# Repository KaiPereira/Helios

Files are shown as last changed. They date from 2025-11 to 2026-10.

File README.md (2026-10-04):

# Helios - Solar Powered LoRa Weather Station

Photo of Helios

Helios is a small, solar powered LoRa weather station, in Pi Zero 2W form factor! It's designed for extremely low power consumption, small price, expandability and hobby purposes! It has a couple onboard sensors for temperature, humidity, pressure and light, but it's mostly designed to be your own little customizable node!

## Custom Features
- 150MHz to 960MHz LoRa SMA antenna, up to +22 dBm
- Solar powered battery charging up to 18V
- 300mA peak power consumption
- Pi Zero 2W form factor
- USB-C programming and power
- 20 programmable GPIO's for expandability
- Temperature, humidity, pressure and ambient light sensors

## PCB Design

Helios is designed to be a low-cost PCB and is a 4 layer PCB, with a SIGNAL/GND/PWR/SIGNAL stackup! 




It's built off the STM32L072 MCU, using the SX1262 LoRa transceiver with the 0900FM filter and the PE4259 RF switch! It's a classic SMA antenna that broadcasts temperature, humidity, pressure and ambient light from the BME280 and BH1750! 

The board can be powered off of USB-C, or solar powered battery charging with the SPV1050 alongside very minimal power usage!






## Manufacturing

The PCB is fairly simple to manufacture. You can get them from JLC, PCBWay or hand-solder it with a stencil and hotplate! If you want the board to be cheaper, just remove the sensors and other unnecessary things you don't need.

The gerbers (PCB.zip), BOM and CPL are located in the [production folder](/TRANSCEIVER_PCB/production/), and there's also a link to the solar panels and battery I used for the project! I got the boards manufactured by PCBWay, so there's a PCBWay specific BOM in that directory too!

I've created a very minimal case for this project if you want to keep it waterproof while having it active outside, and you can view all the files for that in the [CAD folder](https://github.com/KaiPereira/Helios/tree/master/CAD)! Here's an [Onshape link](https://cad.onshape.com/documents/da47fca73387cbfcd2fcd0da/w/e0853c342d07596ecafe782f/e/20c20d8fae7f9e025aea9deb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) too!

## Firmware

Programming the board is really simple! Customize the firmware to your liking, plug in the USB-C and then run:

```
pio run -t upload
```

## Contributions

Thanks so much to PCBWay and Hack Club for sponsoring this project! Another big thanks to the guys in the KiCad discord server for their help and reviews of the board :D

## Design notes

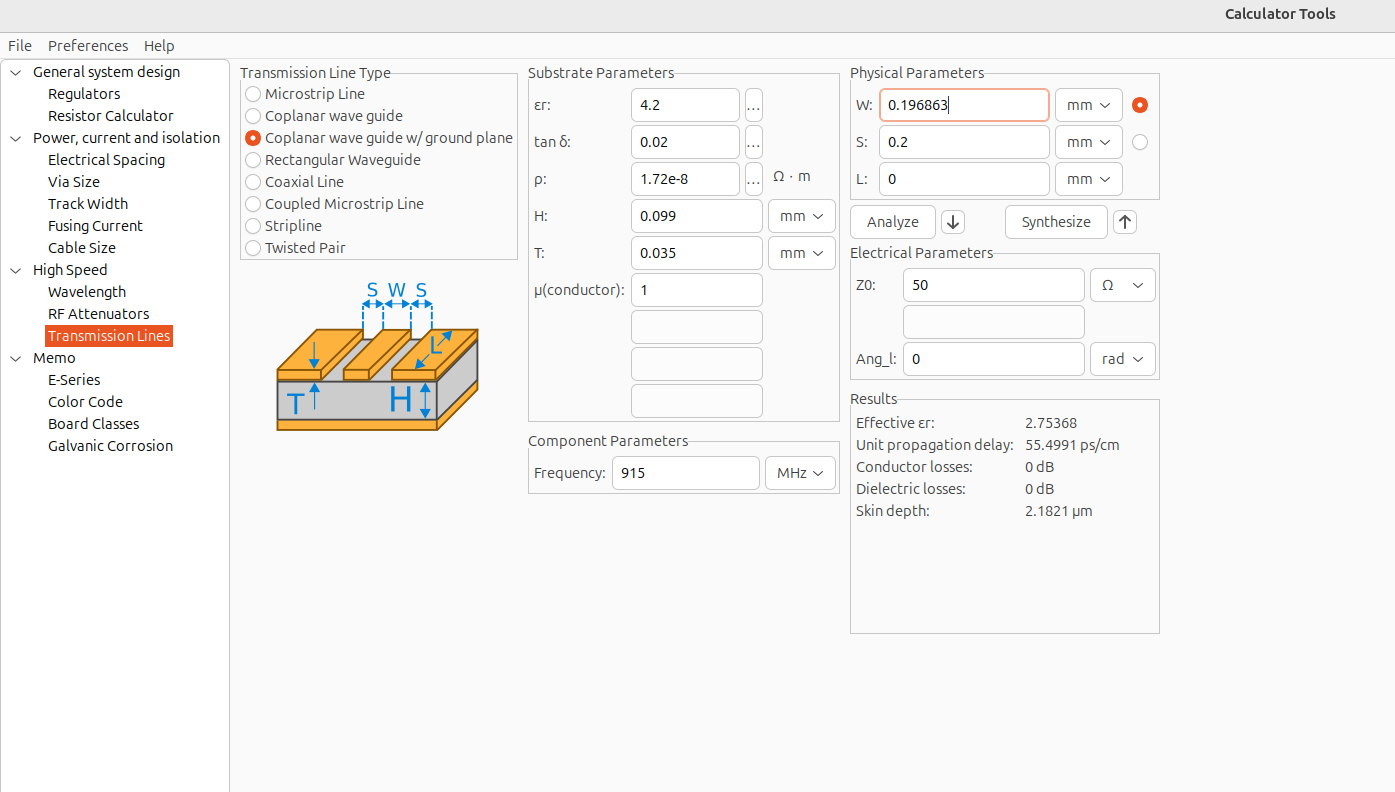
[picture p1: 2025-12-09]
images/Pasted image 20251208185241.png

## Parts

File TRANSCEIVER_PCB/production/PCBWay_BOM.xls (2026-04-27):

PCBWay Bom Quotation, Product No.:T-1K5W971089A
Item # | *Designator | *Qty | Manufacturer | *Mfg Part # | Description / Value | Vendor Part # | *Package/Footprint | Your Instructions / Notes | *Unit Price(5 units) | *Total | *Delivery Time | *Actual Purchase Mfg Part # | *PCBWay Note | Customer Reply | PCBWay Update
1 | C1, C17, C18 | 3 | Samsung Electro-Mechanics | CL10B105MO8NNWC | 1uF | 1276-6524-1-ND | 603 |  | $0.074 | $1.110
2 | C10 | 1 | KEMET | C0402C103K3REC7411 | 10nF | 399-C0402C103K3REC7411CT-ND | 402 |  | $0.158 | $0.790
3 | C11, C13, C19, C2, C20, C29, C30, C31, C32, C4, C5, C6, C7, C8 | 14 | Murata Electronics | GRM155R71H104KE14J | 0.1uF | 490-13342-1-ND | 402 |  | $0.008 | $0.560
4 | C12, C14, C3 | 3 | Samsung Electro-Mechanics | CL21A475KAQNNNE | 4.7uF | 1276-1244-1-ND | 805 |  | $0.074 | $1.110
5 | C15, C16 | 2 | Murata Electronics | GJM1555C1H180GB01D | 18pF | 490-8082-1-ND | 402 |  | $0.101 | $1.010
6 | C21 | 1 | Samsung Electro-Mechanics | CL10B474KO8VPJC | 470nF | 1276-CL10B474KO8VPJCCT-ND | 603 |  | $0.231 | $1.155
7 | C22 | 1 | KEMET | C0402C102K5RECTU | 1nF | 399-C0402C102K5RECTUCT-ND | 402 |  | $0.158 | $0.790
8 | C23 | 1 | Murata Electronics | GRM1555C1H390JA01D | 39pF | 490-5871-1-ND | 402 |  | $0.158 | $0.790
9 | C24, C25 | 2 | Murata Electronics | GRM1555C2A3R3CA01D | 3.3pF | 490-7287-1-ND | 402 |  | $0.095 | $0.950
10 | C26 | 1 | KEMET | C0603C473K4RECAUTO | 47nF | 399-17881-1-ND | 603 |  | $0.368 | $1.840
11 | C27 | 1 | YAGEO | CC0402JRNPO9BN470 | 47pF | 311-1021-1-ND | 402 |  | $0.126 | $0.630
12 | C28, C33 | 2 | Samsung Electro-Mechanics | CL05C080DB51PNC | 8pF | 1276-CL05C080DB51PNCCT-ND | 402 |  | $0.095 | $0.950
13 | C9 | 1 | Panasonic Industry | EEH-ZC1V470P | 47uF | P15473CT-ND | C_Elec_6.3x5.4 |  | $2.205 | $11.025
14 | D1, D2, D3, D5 | 4 | Shenzhen Slkormicro Semicon Co., Ltd. | 1N5819WS | 1N5819WS | 5399-1N5819WSCT-ND | D_SOD-323 |  | $0.041 | $0.820
15 | D4 | 1 | Würth Elektronik | 150060VS75003 | LED | 732-150060VS75003CT-ND | 603 |  | $0.656 | $3.280 | 7-10 Workdays
16 | FB1, FB2 | 2 | Shenzhen Sunlord Electronics Co., Ltd. | GZ1608E601TF | GZ1608D601TF | 3442-GZ1608E601TFCT-ND | 603 |  | $0.011 | $0.110 |  |  | The quoted part number is [GZ1608E601TF], not [GZ1608D601TF] as specified in description
17 | FL1 | 1 | Johanson Technology Inc. | 0900FM15K0039001E | 0900FM15K0039E | 712-0900FM15K0039001ECT-ND | Balun_Johanson_0900FM15K0039 |  | $1.316 | $6.580 | 7-10 Workdays |  | The quoted part number is [0900FM15K0039001E], not [0900FM15K0039E] as specified in description
18 | J1 | 1 | GCT | USB4105-GF-A-120 | USB_C_Receptacle_USB2.0_16P | 2073-USB4105-GF-A-120CT-ND | USB_C_Receptacle_HRO_TYPE-C-31-M-12 |  | $0.978 | $4.890 |  |  | The quoted part number is [USB4105-GF-A-120], not [TYPE-C-31-M-12] as specified in description
19 | J2 | 1 | Amphenol Anytek | YO0201500000G | Screw_Terminal_01x02 | 609-4725-ND | TerminalBlock_Phoenix_PT-1,5-2-3.5-H_1x02_P3.50mm_Horizontal |  | $1.031 | $5.155
20 | J3 | 1 | JST Sales America Inc. | B2B-PH-K-S | Conn_01x02 | 455-1704-ND | JST_PH_B2B-PH-K_1x02_P2.00mm_Vertical |  | $0.201 | $1.005
21 | J4 | 1 | Molex | 0732511153 | LoRa Antenna | 900-0732511153-ND | SMA_Molex_73251-1153_EdgeMount_Horizontal |  | $6.611 | $33.055 | 7-10 Workdays
22 | J6 | 1 | Würth Elektronik | 61304021121 | Conn_02x20_Odd_Even | 732-5310-ND | PinHeader_2x20_P2.54mm_Vertical |  | $1.896 | $9.480
23 | L1 | 1 | Shenzhen Sunlord Electronics Co., Ltd. | MWSA0402S-220MT | 22uH | 3442-MWSA0402S-220MTCT-ND | L_Sunlord_MWSA0402S |  | $0.193 | $0.965
24 | L2 | 1 | TDK | MLZ2012M150WT000 | 15uH | 445-6397-1-ND | L_TDK_MLZ2012_h1.25mm |  | $0.171 | $0.855
25 | L3 | 1 | Murata Electronics | LQW15AN9N1G0ZD | 9.1nH | 490-LQW15AN9N1G0ZDCT-ND | 402 |  | $0.161 | $0.805
26 | L4 | 1 | Murata Electronics | LQW18AN47NJ00D | 47nH | 490-6895-1-ND | 603 |  | $0.121 | $0.605
27 | R1, R11, R12 | 3 | YAGEO | RC0402FR-0710KL | 10K | 311-10.0KLRCT-ND | 402 |  | $0.015 | $0.225
28 | R10 | 1 | YAGEO | RC0402FR-07100RL | 100 | 311-100LRCT-ND | 402 |  | $0.032 | $0.160
29 | R15, R2, R3 | 3 | YAGEO | RC0402FR-075K1L | 5.1k | 311-5.10KLRCT-ND | 402 |  | $0.015 | $0.225
30 | R4 | 1 | Stackpole Electronics Inc | RMCF0603FT10M0 | 10M | RMCF0603FT10M0CT-ND | 603 |  | $0.053 | $0.265
31 | R5 | 1 | YAGEO | RC0402FR-071ML | 1M | 311-1.00MLRCT-ND | 402 |  | $0.032 | $0.160
32 | R6 | 1 | Panasonic Industry | ERJ-2GEJ565X | 5.6M | P5.6MJCT-ND | 402 |  | $0.116 | $0.580
33 | R7 | 1 | YAGEO | RC0402FR-076M2L | 6.2M | 13-RC0402FR-076M2LCT-ND | 402 |  | $0.032 | $0.160
34 | R8 | 1 | YAGEO | RC0603JR-07510KL | 510K | 311-510KGRCT-ND | 603 |  | $0.053 | $0.265
35 | R9 | 1 | YAGEO | RC0402FR-072M7L | 2.7M | 13-RC0402FR-072M7LCT-ND | 402 |  | $0.032 | $0.160
36 | SW1, SW2 | 2 | Alps Alpine | SKRPACE010 | SKRPACE010 | 4809-SKRPACE010CT-ND | SW_Push_SPST_NO_Alps_SKRK |  | $0.091 | $0.910
37 | TP1, TP2, TP3, TP4, TP5, TP6, TP7, TP8 | 8 |  |  | TestPoint |  | TestPoint_Pad_D1.5mm | [DNP ]; |  |  |  |  | [DNP ];
38 | TP9 | 1 |  |  | Charging TP |  | TestPoint_Pad_D1.5mm | [DNP ]; |  |  |  |  | [DNP ];
39 | U1 | 1 | STMicroelectronics | STM32L072CBT6 | STM32L072CBT6 | 497-17503-ND | LQFP-48_7x7mm_P0.5mm |  | $2.777 | $13.885
40 | U3 | 1 | STMicroelectronics | SPV1050TTR | SPV1050TTR | 497-15978-1-ND | WQFN-20-1EP_3x3mm_P0.4mm_EP1.7x1.7mm |  | $3.260 | $16.300
41 | U4 | 1 | Semtech Corporation | SX1262IMLTRT | SX1262IMLTRT | SX1262IMLTRTCT-ND | QFN-24-1EP_4x4mm_P0.5mm_EP2.6x2.6mm |  | $3.019 | $15.095
42 | U5 | 1 | Torex Semiconductor Ltd | XC6206P332MR-G | XC6206P332MR-G | 893-XC6206P332MR-GCT-ND | SOT-23-3 |  | $0.262 | $1.310
43 | U6 | 1 | pSemi | 4259-63 | PE4259-63 | 1046-1011-1-ND | SOT-363_SC-70-6 |  | $1.092 | $5.460
44 | U8 | 1 | Rohm Semiconductor | BH1750FVI-TR | BH1750FVI | BH1750FVICT-ND | WSOF-6_L2.6-W1.6-P0.50-TL-EP |  | $1.087 | $5.435
45 | U9 | 1 | Bosch Sensortec | BME280 | BME280 | 828-1063-1-ND | Bosch_LGA-8_2.5x2.5mm_P0.65mm_ClockwisePinNumbering |  | $5.555 | $27.775
46 | Y1 | 1 | EPSON | FC-135 32.7680KA-A5 | 32.768 kHz | SER4103CT-ND | Crystal_SMD_3215-2Pin_3.2x1.5mm |  | $0.845 | $4.225
47 | Y2 | 1 | ECS Inc. | ECS-320-8-37B-CKY-TR | 32MHz | 50-ECS-320-8-37B-CKY-TRCT-ND | Crystal_SMD_2016-4Pin_2.0x1.6mm |  | $0.656 | $3.280 | 7-10 Workdays
48 |  | 1 | Molex | 2161960001 | BIG ANTENNNNAAA | 900-2161960001-ND | LoRa SMA Molex Antenna | 900-2161960001-ND(the SMA Molex Antenna) screwed onto the SMA connector (900-0732511153-ND) | $10.147 | $50.735 | 7-10 Workdays | 216196-0001
49 |  | 1 | JST Sales America Inc. | PHR-2 |  | 455-1165-ND | JST PHR connector (for battery I chose) | [DNP ]; |  |  |  |  | [DNP ];
50 |  | 1 | JST Sales America Inc. | BPH-002T-P0.5S |  | 455-BPH-002T-P0.5S-ND | JST PHR metal contacts (for PHR connector) | [DNP ]; |  |  |  |  | [DNP ];
51 |  | 4 | E-Z LOK | HI-002-WH |  | 5519-HI-002-WH-ND | Heatset Inserts | [DNP ]; |  |  |  |  | [DNP ];
 |  |  |  |  |  |  |  |  | Component Cost | $236.93
 |  |  |  |  |  |  |  |  | Assembly Cost | $29.00
 |  |  |  |  |  |  |  |  | PCB Cost | $25.97
 |  |  |  |  |  |  |  |  | V1 Member 1% off | -$0.55
 |  |  |  |  |  |  |  |  | All Total 5 Units | $291.35

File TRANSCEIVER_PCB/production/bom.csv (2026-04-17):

Designator | Footprint | Quantity | Value | LCSC Part #
C1, C17, C18 | 0603 | 3 | 1uF
C10 | 0402 | 1 | 10nF
C11, C13, C19, C2, C20, C29, C30, C31, C32, C4, C5, C6, C7, C8 | 0402 | 14 | 0.1uF
C12, C14, C3 | 0805 | 3 | 4.7uF
C15, C16 | 0402 | 2 | 18pF
C21 | 0603 | 1 | 470nF
C22 | 0402 | 1 | 1nF
C23 | 0402 | 1 | 39pF
C24, C25 | 0402 | 2 | 3.3pF
C26 | 0603 | 1 | 47nF
C27 | 0402 | 1 | 47pF
C28, C33 | 0402 | 2 | 8pF
C9 | C_Elec_6.3x5.4 | 1 | 47uF
D1, D2, D3, D5 | D_SOD-323 | 4 | 1N5819WS
D4 | 0603 | 1 | LED
FB1, FB2 | 0603 | 2 | GZ1608D601TF
FL1 | Balun_Johanson_0900FM15K0039 | 1 | 0900FM15K0039E
J1 | USB_C_Receptacle_HRO_TYPE-C-31-M-12 | 1 | USB_C_Receptacle_USB2.0_16P
J2 | TerminalBlock_Phoenix_PT-1,5-2-3.5-H_1x02_P3.50mm_Horizontal | 1 | Screw_Terminal_01x02
J3 | JST_PH_B2B-PH-K_1x02_P2.00mm_Vertical | 1 | Conn_01x02
J4 | SMA_Molex_73251-1153_EdgeMount_Horizontal | 1 | LoRa Antenna
J6 | PinHeader_2x20_P2.54mm_Vertical | 1 | Conn_02x20_Odd_Even
L1 | L_Sunlord_MWSA0402S | 1 | 22uH
L2 | L_TDK_MLZ2012_h1.25mm | 1 | 15uH
L3 | 0402 | 1 | 9.1nH
L4 | 0603 | 1 | 47nH
R1, R11, R12 | 0402 | 3 | 10K
R10 | 0402 | 1 | 100
R15, R2, R3 | 0402 | 3 | 5.1k
R4 | 0603 | 1 | 10M
R5 | 0402 | 1 | 1M
R6 | 0402 | 1 | 5.6M
R7 | 0402 | 1 | 6.2M
R8 | 0603 | 1 | 510K
R9 | 0402 | 1 | 2.7M
SW1, SW2 | SW_Push_SPST_NO_Alps_SKRK | 2 | SKRPACE010
TP1, TP2, TP3, TP4, TP5, TP6, TP7, TP8 | TestPoint_Pad_D1.5mm | 8 | TestPoint
TP9 | TestPoint_Pad_D1.5mm | 1 | Charging TP
U1 | LQFP-48_7x7mm_P0.5mm | 1 | STM32L072CBT6
U3 | WQFN-20-1EP_3x3mm_P0.4mm_EP1.7x1.7mm | 1 | SPV1050TTR
U4 | QFN-24-1EP_4x4mm_P0.5mm_EP2.6x2.6mm | 1 | SX1262IMLTRT
U5 | SOT-23-3 | 1 | XC6206P332MR-G
U6 | SOT-363_SC-70-6 | 1 | PE4259-63
U8 | WSOF-6_L2.6-W1.6-P0.50-TL-EP | 1 | BH1750FVI
U9 | Bosch_LGA-8_2.5x2.5mm_P0.65mm_ClockwisePinNumbering | 1 | BME280
Y1 | Crystal_SMD_3215-2Pin_3.2x1.5mm | 1 | 32.768 kHz
Y2 | Crystal_SMD_2016-4Pin_2.0x1.6mm | 1 | 32MHz

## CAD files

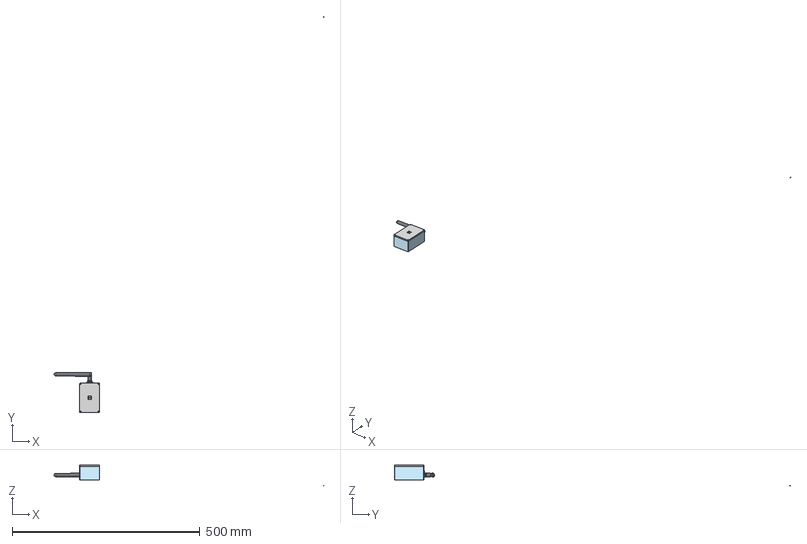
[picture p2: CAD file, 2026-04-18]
CAD/FULL_ASSEMBLY (don't print).step
717.9 x 1053.5 x 55.3 mm
ant x 3
conn_body
socket
SMA_threads
WSOF-6_L1.6-W2.6-H0.8-P0.50 x 4
C_0402_1005Metric x 24
USB_C_Receptacle_GCT_USB4105-xx-A_16P_TopMnt_Horizontal x 36
L_TDK_MLZ2012_h1.25mm
C_0805_2012Metric x 3
C_0603_1608Metric x 5
SOT-23-3
PinHeader_2x20_P2.54mm_Vertical
Crystal_SMD_3215-2Pin_3.2x1.5mm
R_0402_1005Metric x 11
Bosch_LGA-8_2.5x2.5mm_P0.65mm_ClockwisePinNumbering
SMA_Molex_73251-1153_EdgeMount_Horizontal
SW_Push_SPST_NO_Alps_SKRK x 2
LQFP-48_7x7mm_P0.5mm
JST_PH_B2B-PH-K_1x02_P2.00mm_Vertical
L_0402_1005Metric
C_Elec_6.3x5.4 x 2
D_SOD-323 x 4
SOT-363_SC-70-6
Crystal_SMD_2016-4Pin_2.0x1.6mm
R_0603_1608Metric x 4
LED_0603_1608Metric
TerminalBlock_Phoenix_PT-1,5-2-3.5-H_1x02_P3.50mm_Horizontal
PCB_PCB
.step 1.1.1 x 3
L_0603_1608Metric
.step 1.44.2 x 10
.step 1.44.1
.step 1.44.3
QFN-24-1EP_4x4mm_P0.5mm_EP2.6x2.6mm

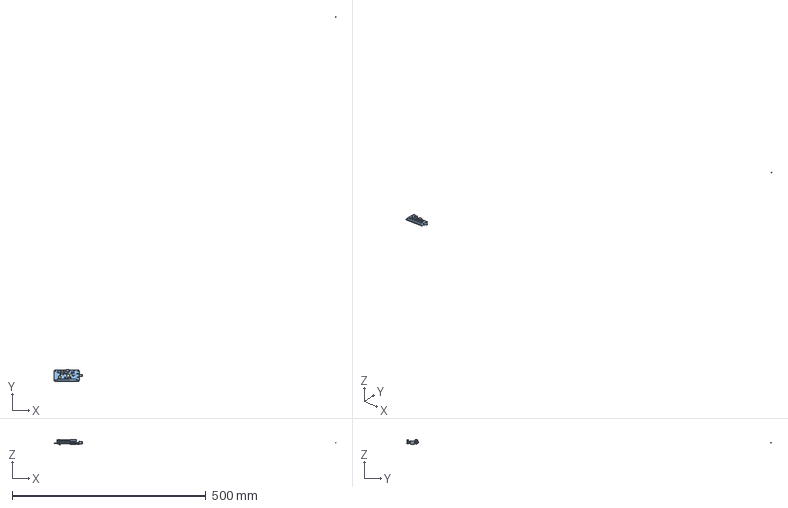
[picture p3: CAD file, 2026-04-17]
TRANSCEIVER_PCB/.step
727.0 x 941.4 x 13.7 mm
.step 1.1.1
QFN-24-1EP_4x4mm_P0.5mm_EP2.6x2.6mm
R_0402_1005Metric x 11
USB_C_Receptacle_GCT_USB4105-xx-A_16P_TopMnt_Horizontal
C_0603_1608Metric x 5
TerminalBlock_Phoenix_PT-1,5-2-3.5-H_1x02_P3.50mm_Horizontal
C_0402_1005Metric x 24
Crystal_SMD_2016-4Pin_2.0x1.6mm
L_0603_1608Metric
D_SOD-323 x 4
LQFP-48_7x7mm_P0.5mm
Bosch_LGA-8_2.5x2.5mm_P0.65mm_ClockwisePinNumbering
L_0402_1005Metric
WSOF-6_L1.6-W2.6-H0.8-P0.50
PinHeader_2x20_P2.54mm_Vertical
L_TDK_MLZ2012_h1.25mm
C_0805_2012Metric x 3
Crystal_SMD_3215-2Pin_3.2x1.5mm
SOT-363_SC-70-6
SW_Push_SPST_NO_Alps_SKRK x 2
JST_PH_B2B-PH-K_1x02_P2.00mm_Vertical
SOT-23-3
.step 1.44.1
.step 1.44.2
.step 1.44.3
R_0603_1608Metric x 4
C_Elec_6.3x5.4
SMA_Molex_73251-1153_EdgeMount_Horizontal
LED_0603_1608Metric
PCB_PCB

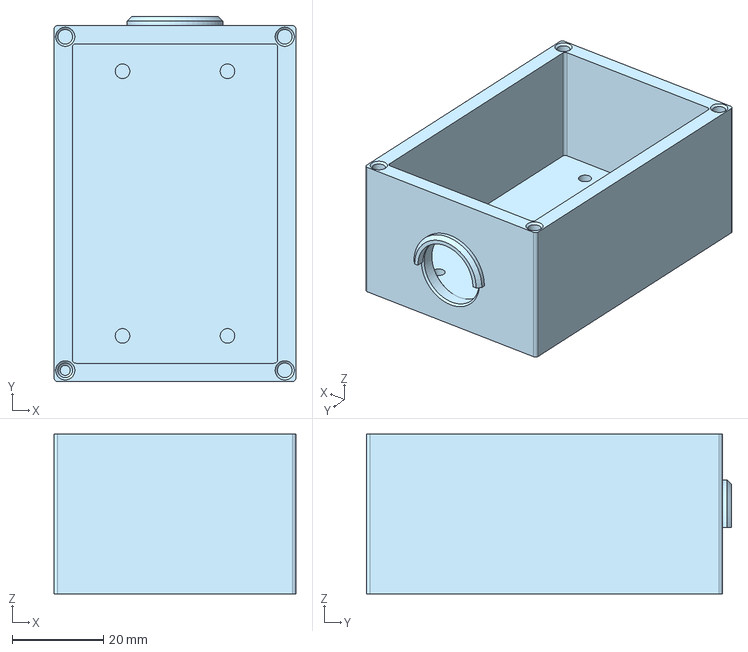
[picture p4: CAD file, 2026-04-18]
CAD/CONTAINER_BOTTOM.step
53.0 x 80.0 x 35.0 mm

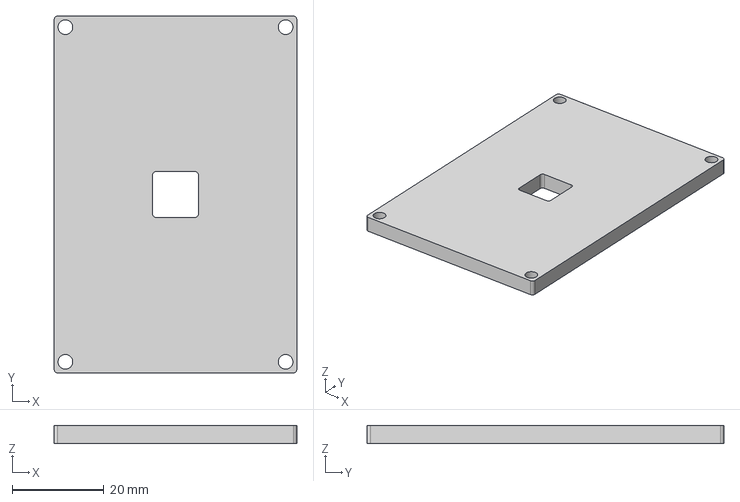
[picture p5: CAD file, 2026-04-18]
CAD/CONTAINER_TOP.step
53.0 x 78.0 x 4.00 mm

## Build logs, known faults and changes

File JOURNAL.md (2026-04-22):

---
title: Helios
author: Kai Pereira
description: Solar powered, LoRa weather station transceiver and receiver!
created_at: 2025-10-26
---
## Day 1 - Starting Helios :D - 5 Hours

I've decided to work on speedrunning a little project to learn more about radio's and to improve my STM32 skills, because I absolutely love their SoC's!!

The project is going to be a little solar transceiver and receiver, the transceiver will use a battery with solar panels, and be able to check the weather and soil, and the receiver will be a little antenna on my homeserver and I'll put that on my website!!

So the first thing I did is flesh out some of the details. I have a very good vision of the project in my head, so I didn't write too much down, but I got some of the components down:

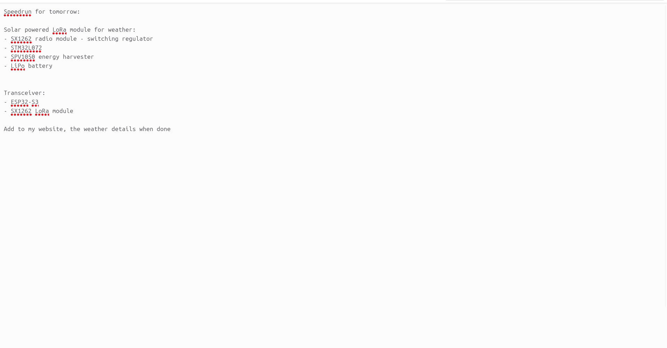
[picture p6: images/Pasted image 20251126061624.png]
Pasted image 20251126061624.png


Next, I'm going to start on the MCU! I'm using the STM32L072 because it's really low power and I don't need too many peripherals! So I wired the really simple stuff:

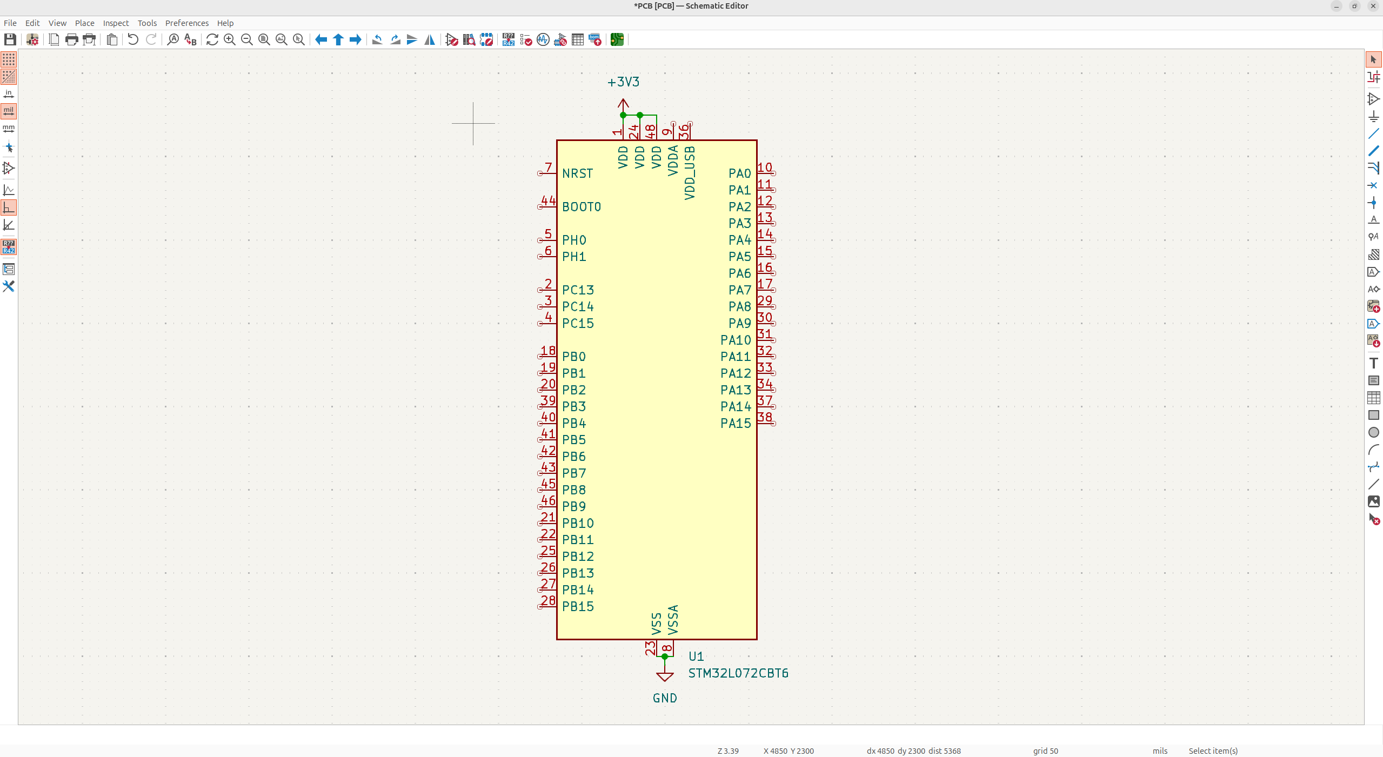
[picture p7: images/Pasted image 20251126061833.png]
Pasted image 20251126061833.png


Next, I need to add a ferrite bead on VDDA to filter the high frequency noise so it doesn't affect the analog aspects of my MCU!

I decided to use the GZ1608D601TF ferrite bead, because it has filtering at 600 ohms, and my MCU isn't drawing much current so I don't need anything crazy, and it'll have low drop:

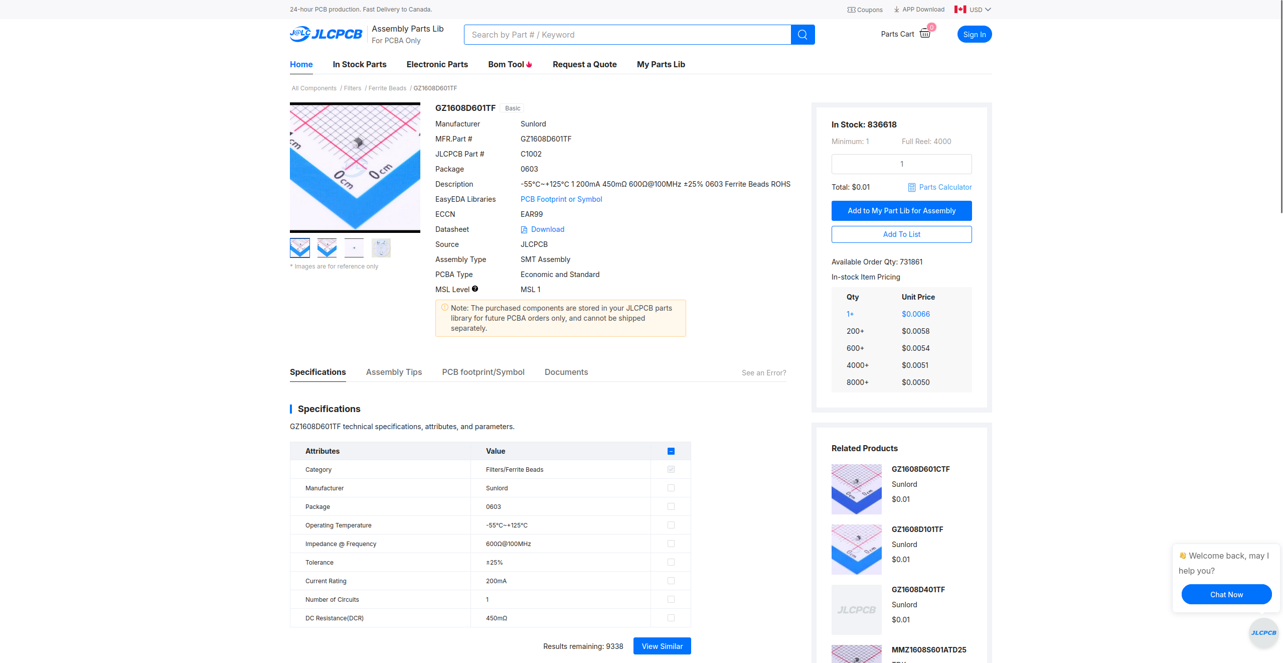
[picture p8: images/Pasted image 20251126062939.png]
Pasted image 20251126062939.png


I also added some decoupling after the ferrite bead, a bulk to smooth the voltage drop, and a smaller one for the MCU:

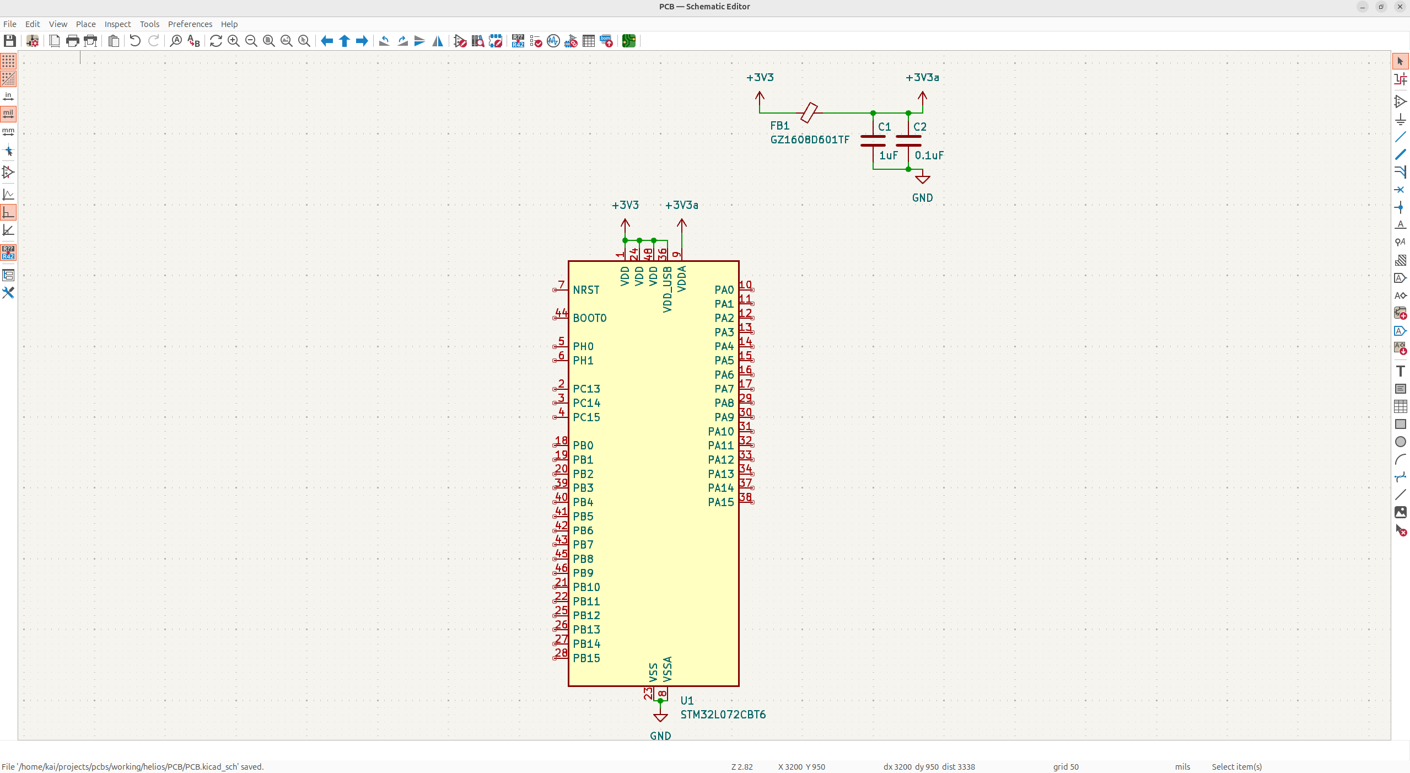
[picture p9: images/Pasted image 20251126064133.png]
Pasted image 20251126064133.png


And then there's 4 VDD pins (one VDD_USB), and I already did VDDA, so I do one bulk cap for the group, and then one 100nF per VDD pin:

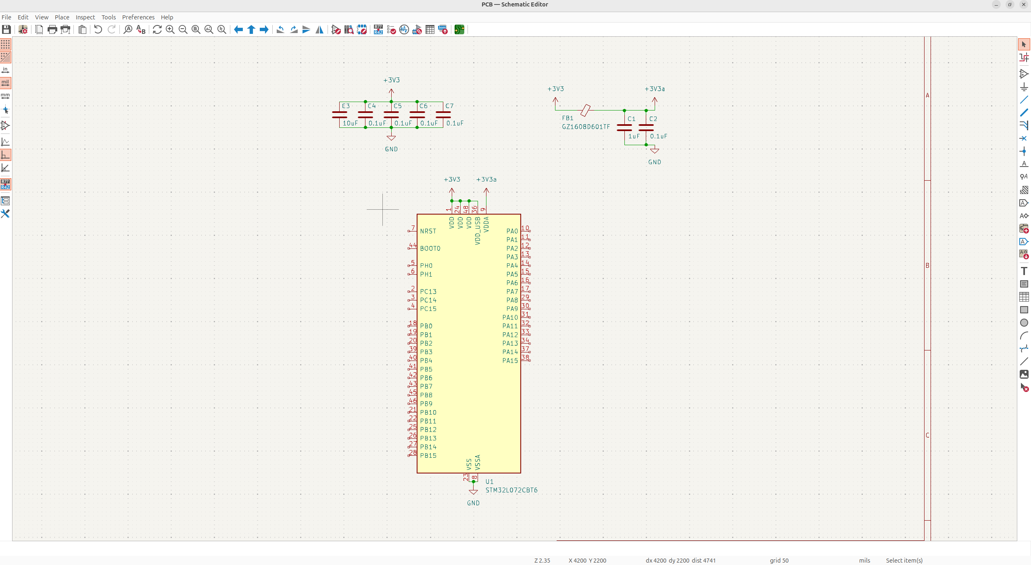
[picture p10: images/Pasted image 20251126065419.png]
Pasted image 20251126065419.png


Next, I need to add my boot and reset button. The reset button has a 100nF cap so that the module doesn't accidentally reset from a voltage spike!

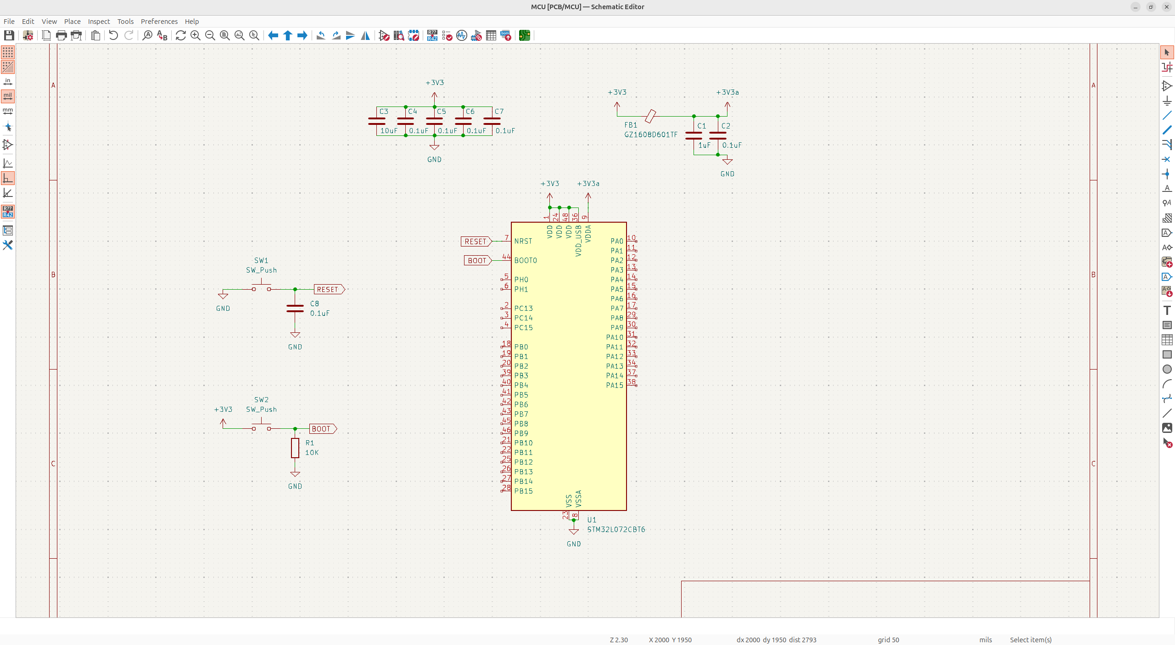
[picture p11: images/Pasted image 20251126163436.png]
Pasted image 20251126163436.png


Next, I need to work on my power systems! I'm going to add USB-C so that I can actually program this thing:

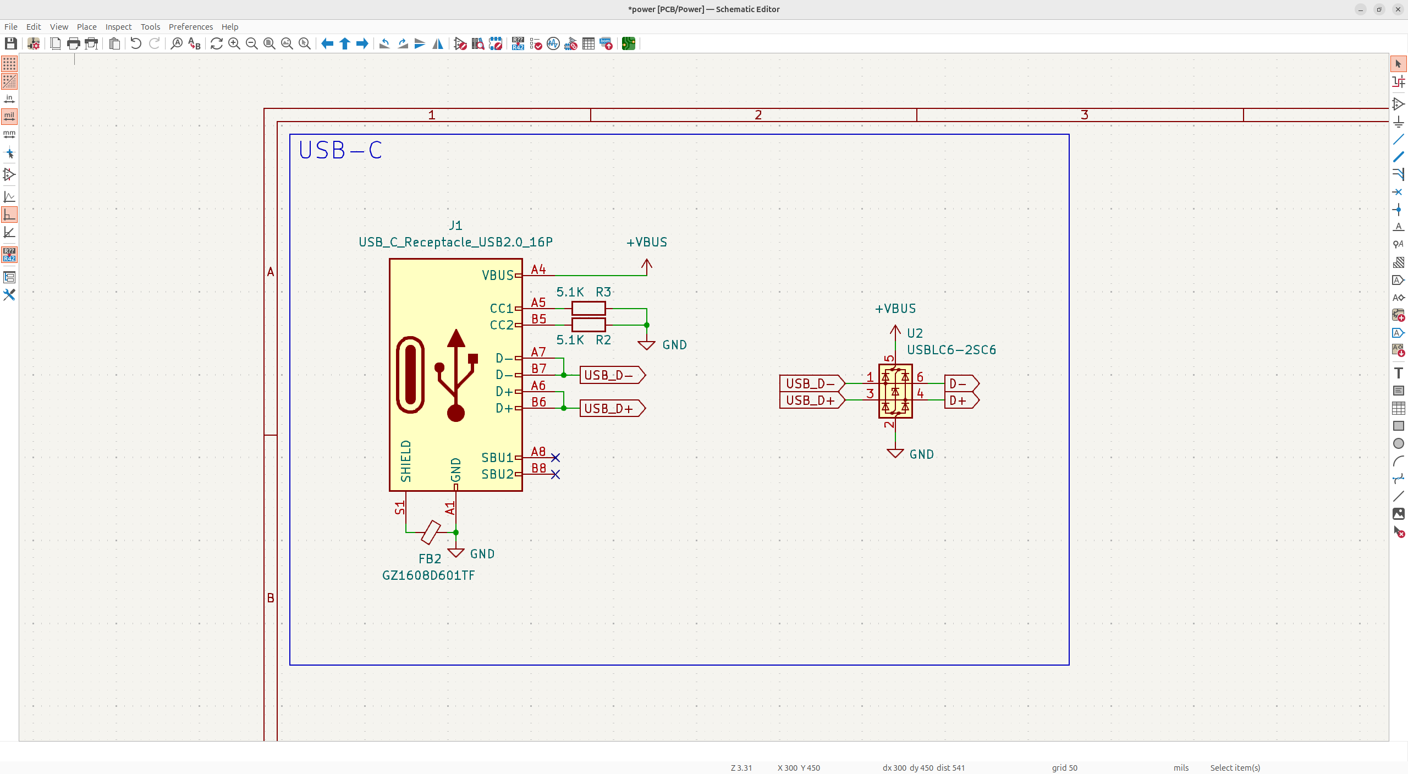
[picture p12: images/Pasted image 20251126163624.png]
Pasted image 20251126163624.png


You can see I use a ferrite bead on shield so that it doesn't act as a weak antenna, and I also added ESD protection!

And that kind of concluded my first day working on the project! 

## Day 2 - Main Systems - 6 Hours

Day 2 is all about getting the main systems in so that the board is actually programmable and works, but without any of the real features.

So the first thing I added was the connectors for the battery and solar panels! I decided to use a screw terminal for the solar panels so that like 90% of solar panels would work with this board! And then the battery will probably just be a JST connector or screw terminals, I need to do a bit more research on the most common thing to use:

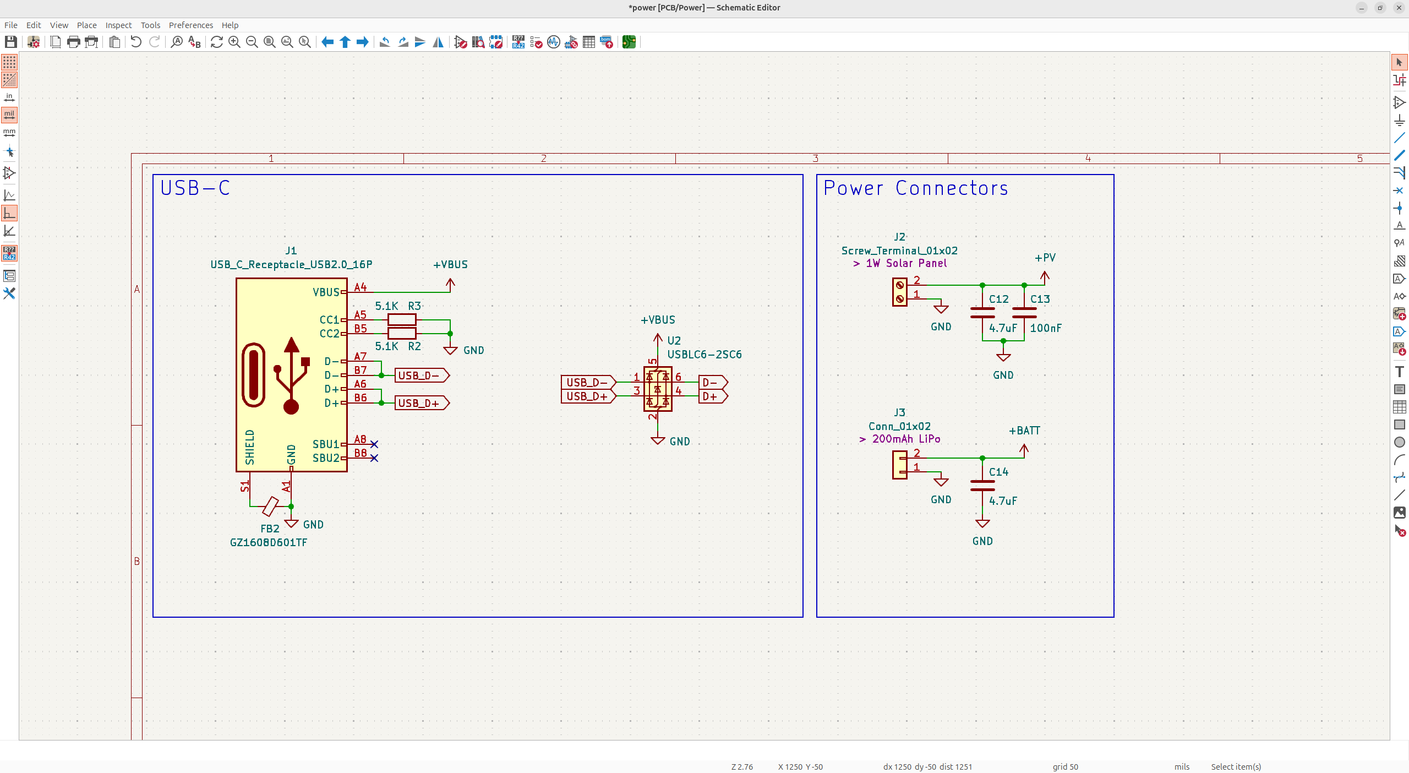
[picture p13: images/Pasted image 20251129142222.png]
Pasted image 20251129142222.png


Next I need to add the actual energy harvester for the solar panels. This handles everything from the protection, to charging, etc, it's really cool! I decided to use the SPV1050 because it's really low power and not as complicated as some of the other modules.

This wiring took me FOREVER, but I got it pretty clean:

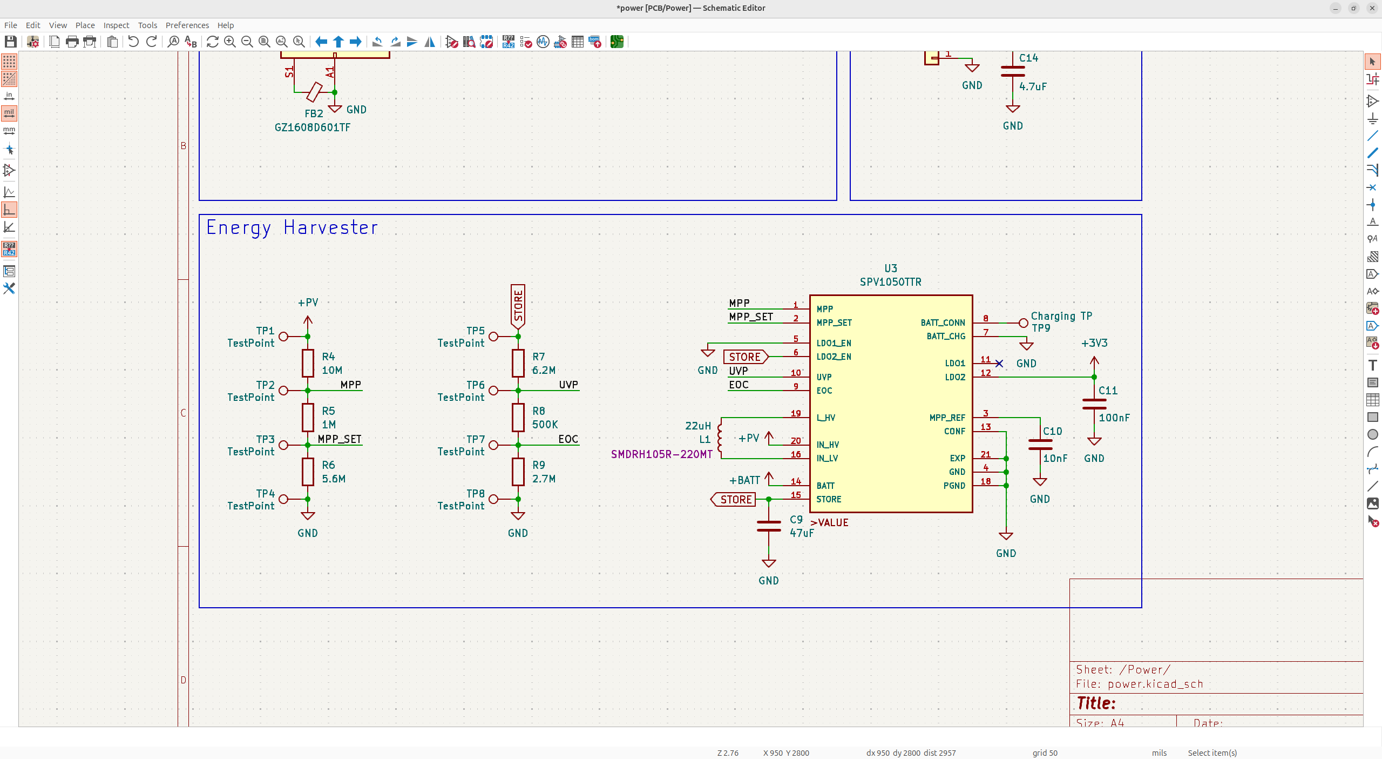
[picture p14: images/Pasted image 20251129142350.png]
Pasted image 20251129142350.png


It took me quite a long time for a couple reasons:
- The voltage divider was really confusing, I ended up just copying another design and tried to BOM optimize it the most possible!
- I wanted to keep the schematic really clean, so I was continuously modifying the symbol so that it looks really good!
- And then the actual wiring was pretty difficult because the application circuit wasn't complete!

I learned a lot about how the different parts like how the resistor divider actually works and also on storing energy with caps.

Next I needed to step down the LiPo 3.7V to 3V3, I decided not to add battery protection to keep low overhead complexity and most of them include protection these days too! I chose an LDO with a medium dropout, low current, and very low quiescant, because I want something good for battery applications but enough to keep it active!

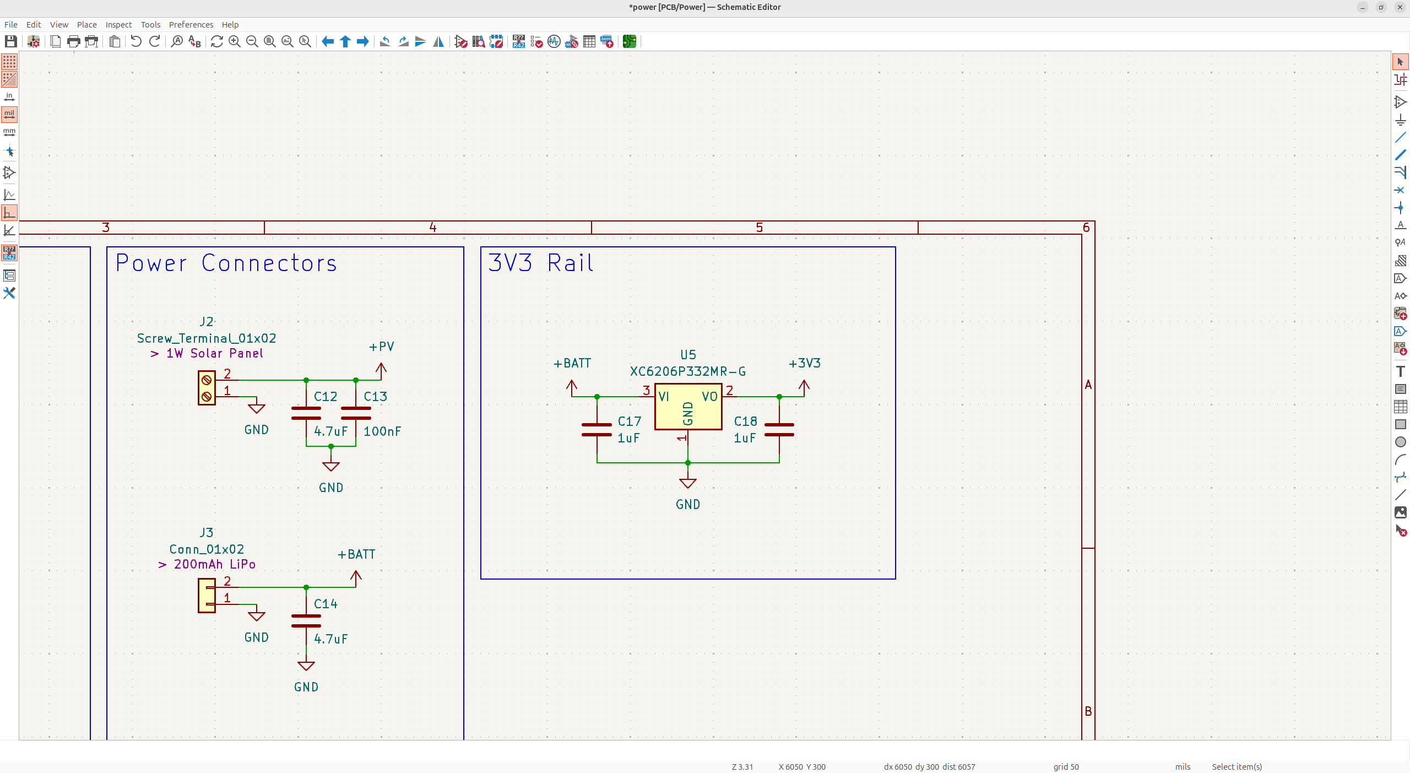
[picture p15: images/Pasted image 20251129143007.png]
Pasted image 20251129143007.png


Next, I tuned up my MCU schematic and double checked stuff, and realized I missed an external crystal I should probably have! I added the 32.768 KHz crystal so that I could keep track of the time in low-power mode so I could send signals accurately from my antenna!

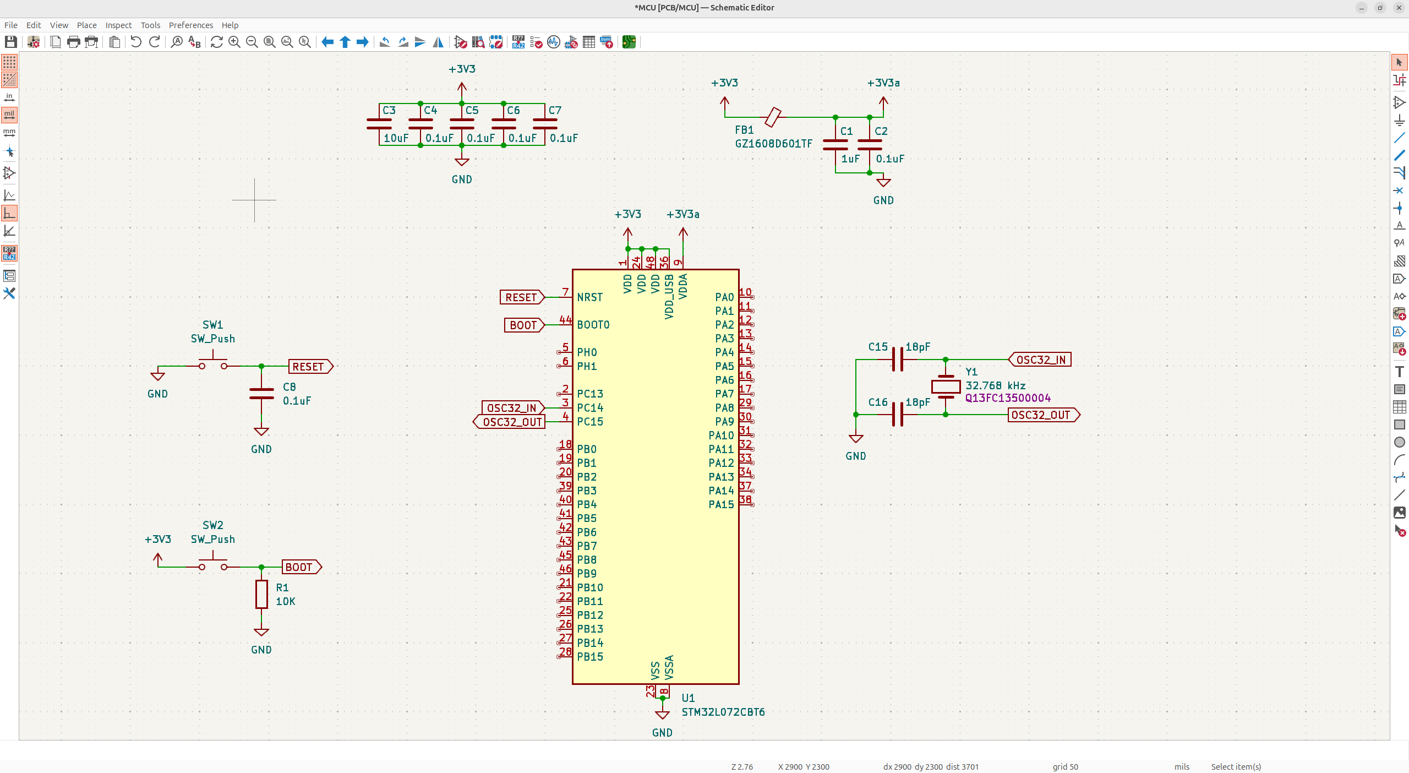
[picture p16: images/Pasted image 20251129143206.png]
Pasted image 20251129143206.png


And then I tuned out for the day, because the SPV1050 wiring took me absolutely forever!! I'm ready to start working on the actual antenna stuff now though, and I think I can lock in and get a bunch done at once!

## Day 3 - RF and Sensor Shenanigans - 8 Hours

Now that I have all my core logic in, I have to add the actual LoRa antenna and transceiver.

There's a couple parts to this:
- The transceiver (SX1262) sends and receives the LoRa radio signals
- The RF switch (PE4259) switches these signals on and off with very little loss so you an just quickly send out a signal and whatnot
- The 0900FM is a filter that cleans up the LoRa signals before they get sent off

So with that in mind, I did all the wiring :D 

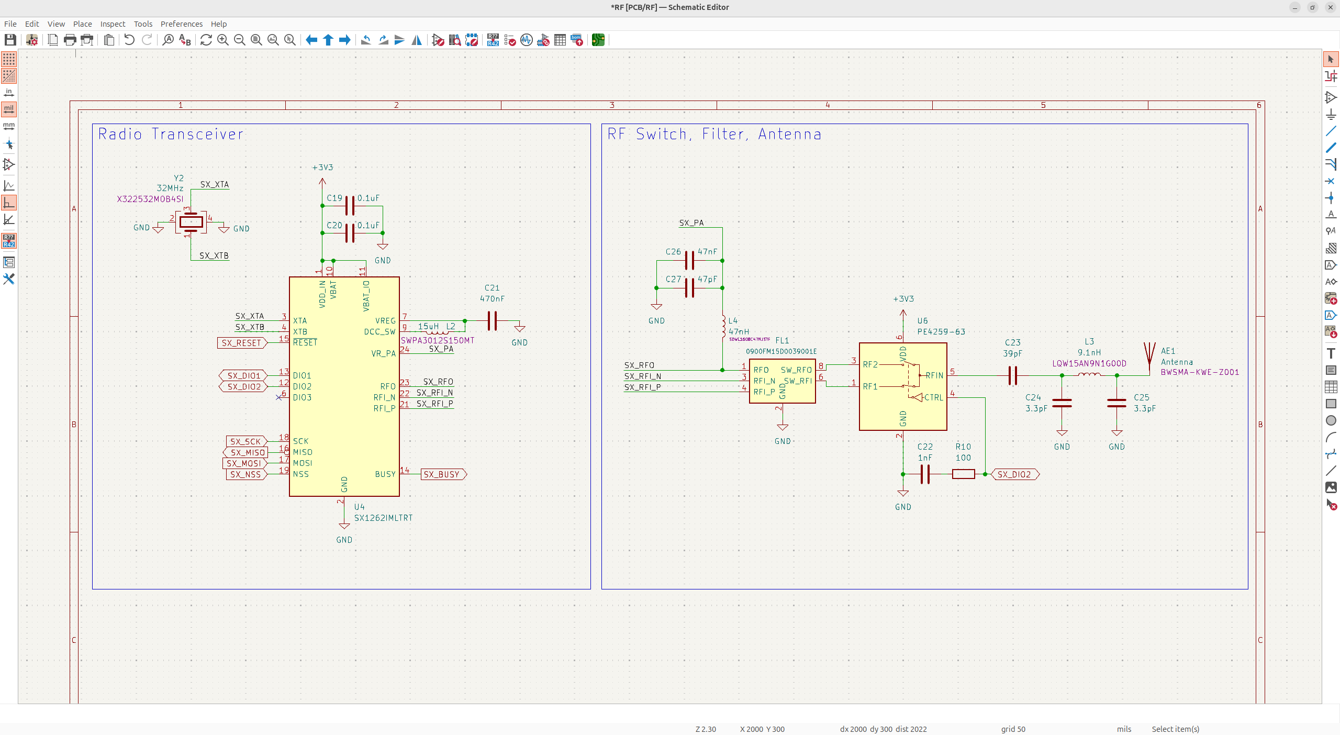
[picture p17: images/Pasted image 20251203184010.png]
Pasted image 20251203184010.png


You'll notice a couple strange things here, the first is the crystal which is used to create a very precise clock to generate the 900 MHz frequencies, it has built in load caps so you don't need any.

You'll also notice an inductor on DCC_SW which gives a higher voltage to the power amplifier on the SX1262 which will let the PA push more current and achieve a higher output power!

Next you'll notice an inductor in parallel with RFO which is part of the RF filter for the power amplifier output. So PA is the power booster, and RFO is the actual signal, PA is boosting this signal and it's going through a matching network which is the capacitors and inductors to achieve a consistent 50ohm impedance.

After that, it goes through the RF filter, and then onto the actual RF switch. You'll notice the signal to control the RF switch (SX_DIO2), has a very small decoupling capacitor. This is a low-pass filter or debounce cap to prevent the switch from actually turning on and off, and it's a really sensitive signal so that's why it's so small. 

And then finally, you'll see what's called a Pi-L Matching Network which is a:
- Series capacitor to provide series reactance for tuning and prevents DC from going into the antenna
- Parallel capacitor which is part of tuning the impedance
- Series inductor to provide more series reactance to match the impedance
- Another parallel capacitor, for more tuning

This just fine tunes our signal even further, and that's our RF circuit! Pretty complicated right! But I hope to learn a lot more about how RF works once I spend more time working on RF boards! 

Next up, I want to add all the sensors onto my board.

I compiled a list of different sensors I could use like temperature, humidity, pressure, soil, etc, and decided on using just 3 components and then breaking out the rest:
- BME280: temperature, humidity, pressure
- Capacitative soil sensor
- BH1750: ambient light detector

And then you'll be able to add your own sensors to customize it using the broken out pins!

It's pretty easy to wire sensors, I did have to make/alter the symbols and go looking for some footprints, but it was relatively easy:

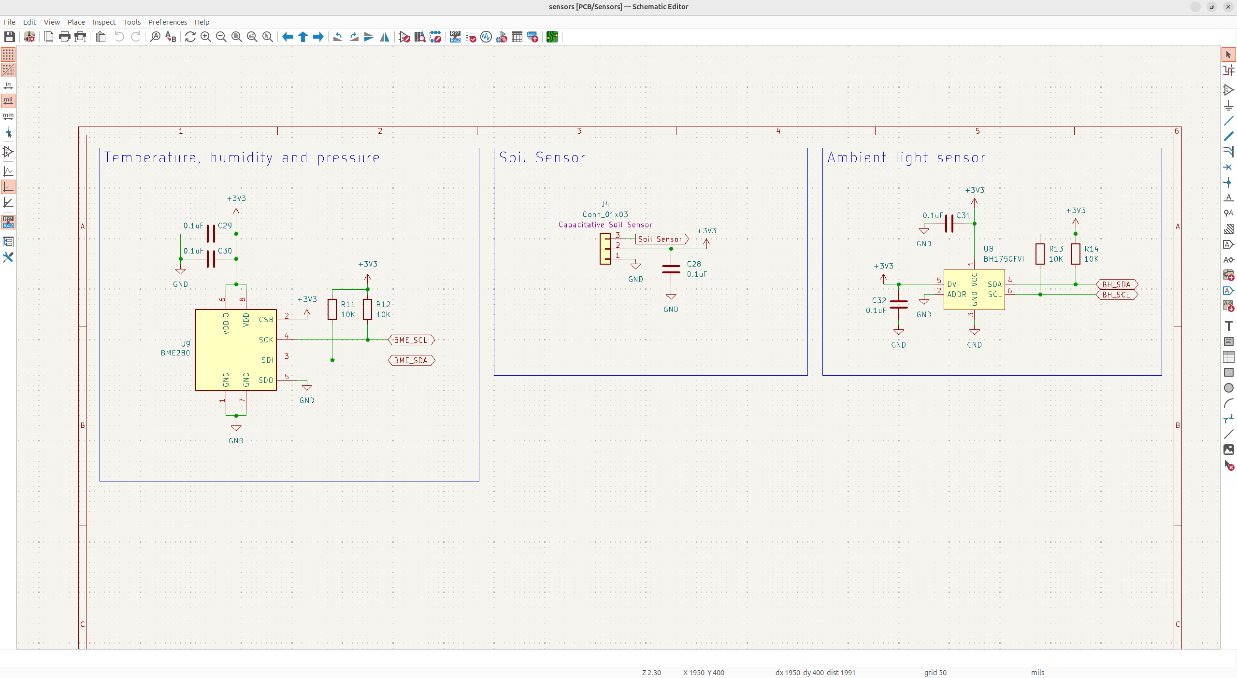
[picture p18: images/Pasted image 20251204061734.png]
Pasted image 20251204061734.png


I decided to split the I2C for my BH1750 and the BME280 because I didn't want any extra programming overhead or to even possibly lose more energy on it.

And with that, I have all the fundamentals of the board in, and now I just have to clean up the mistakes, add the pin headers and footprints, and route the board! 

I went through MANY iterations of the pins headers, intially going with a 2, 1x20 pin headers, into 2, 1x16 pin headers because a lot of pins and I wanted to fit a pi pico form factor, but I ended up going with a 2x20 header and match the pi zero 2w form factor!

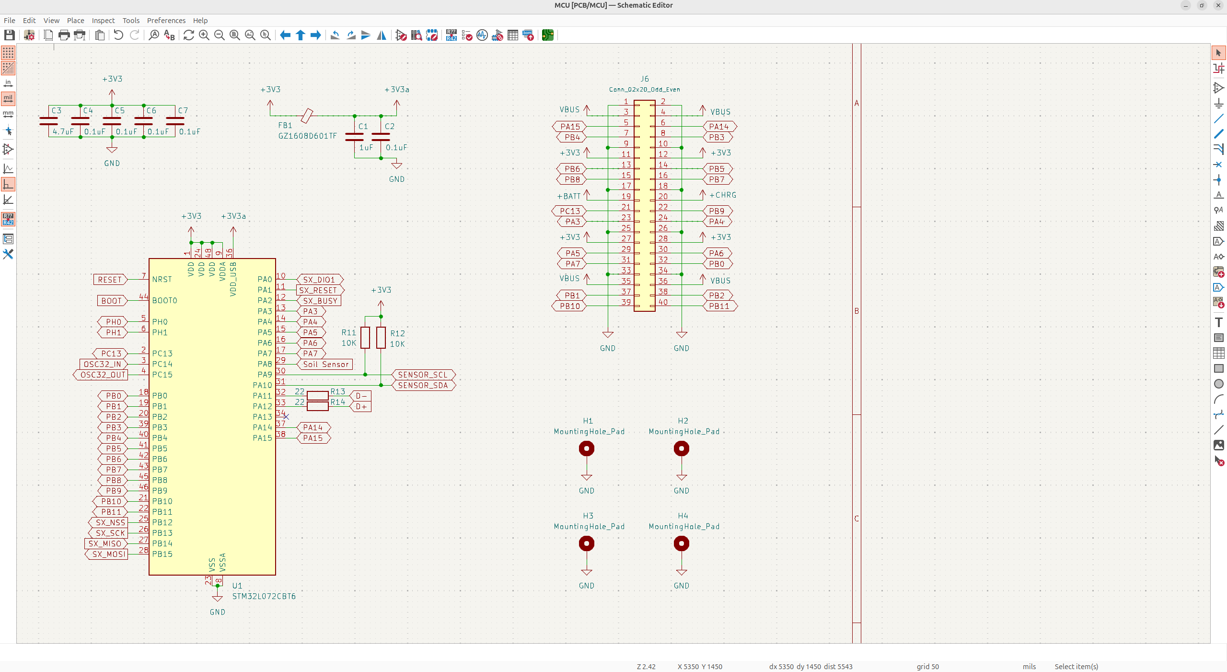
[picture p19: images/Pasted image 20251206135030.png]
Pasted image 20251206135030.png


I also added in the mounting holes, I made these grounded holes so that the RF signals wouldn't become parasitic radiators and might give a bit of shielding.

I had to completely move all the pins to make it the easiest possible routing when the time comes which was insanely time consuming, and I combined the I2C bus for the sensors to save some pins, and added in the USB programming!

And with that, alongside some other minor changes and whatnot, the board schematic is complete!

Tomorrow, I'm going to add in all the extra footprint, and hopefully get the entire layout and some routing in.

## Day 4 - Footprint and PCB time - 7 Hours

Today, I really wanted to get all the footprints in, get the form factor of the pi zero 2w and also layout all the components onto the board and maybe start some routing if I have time!

So I added in all the footprints which was generally pretty boring, and then I made the zero 2w form factor using some fun layout techniques (mostly aligning):

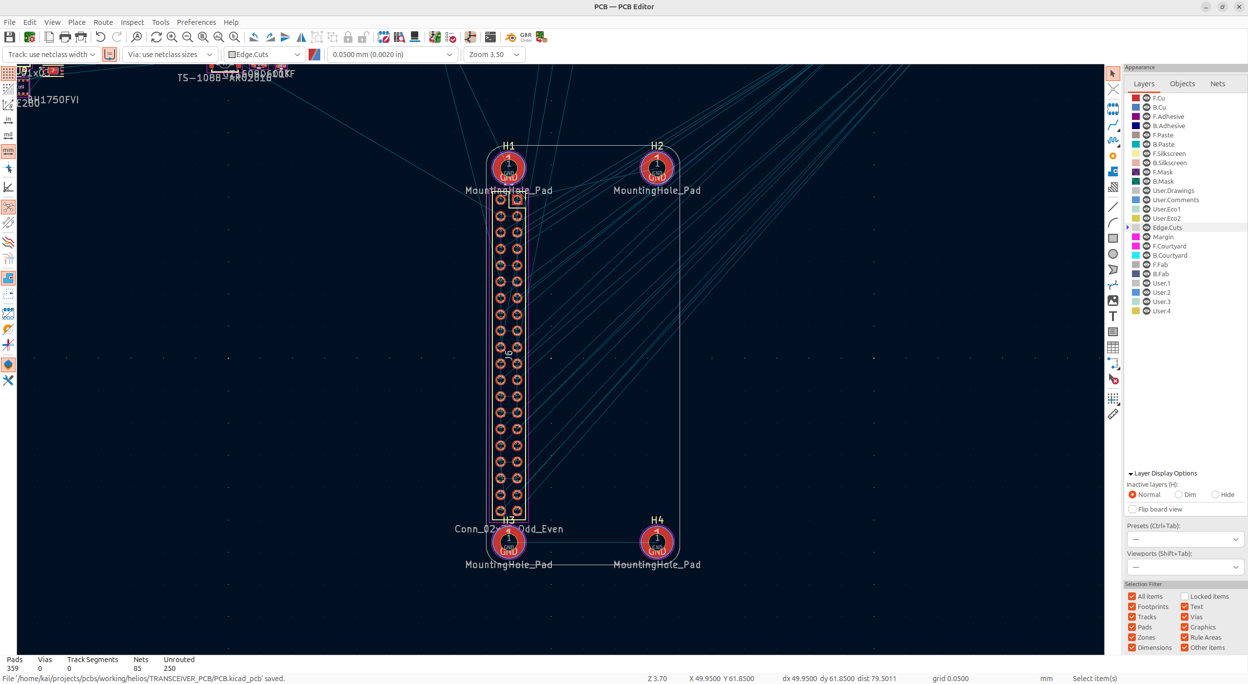
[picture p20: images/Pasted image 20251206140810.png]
Pasted image 20251206140810.png


You can see how all the pins nicely go onto the headers from the MCU which took me a long time to do in the schematic, but it's definitely worth it!

Now I have to lay out all the components onto my PCB. To do this, I'll first make groups, and then slowly add those onto the board.

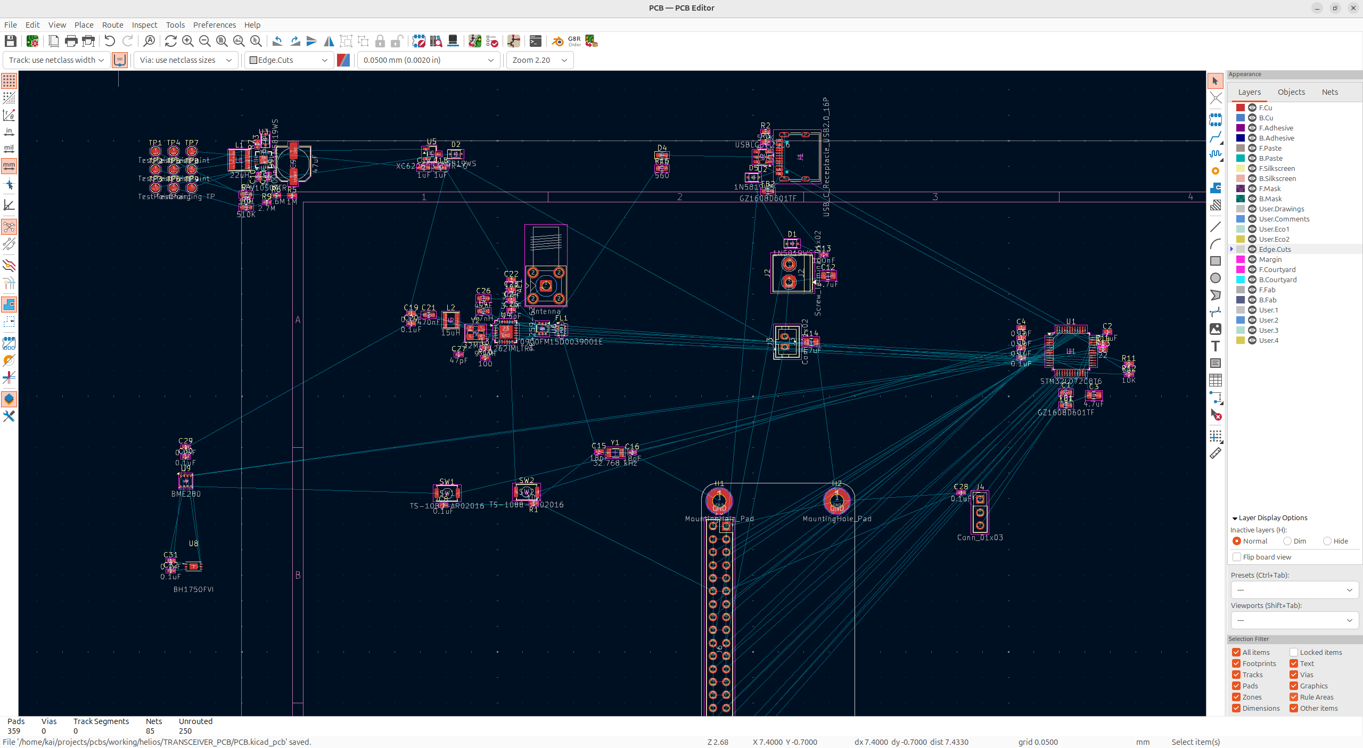
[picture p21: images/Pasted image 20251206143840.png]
Pasted image 20251206143840.png


It's really messy right now, but this makes it much easier to see what components can fit where on the board really nicely! 

After this, I absolutely locked in and cranked out this board in about a day so I'm just going to skip to the whole thing routed:

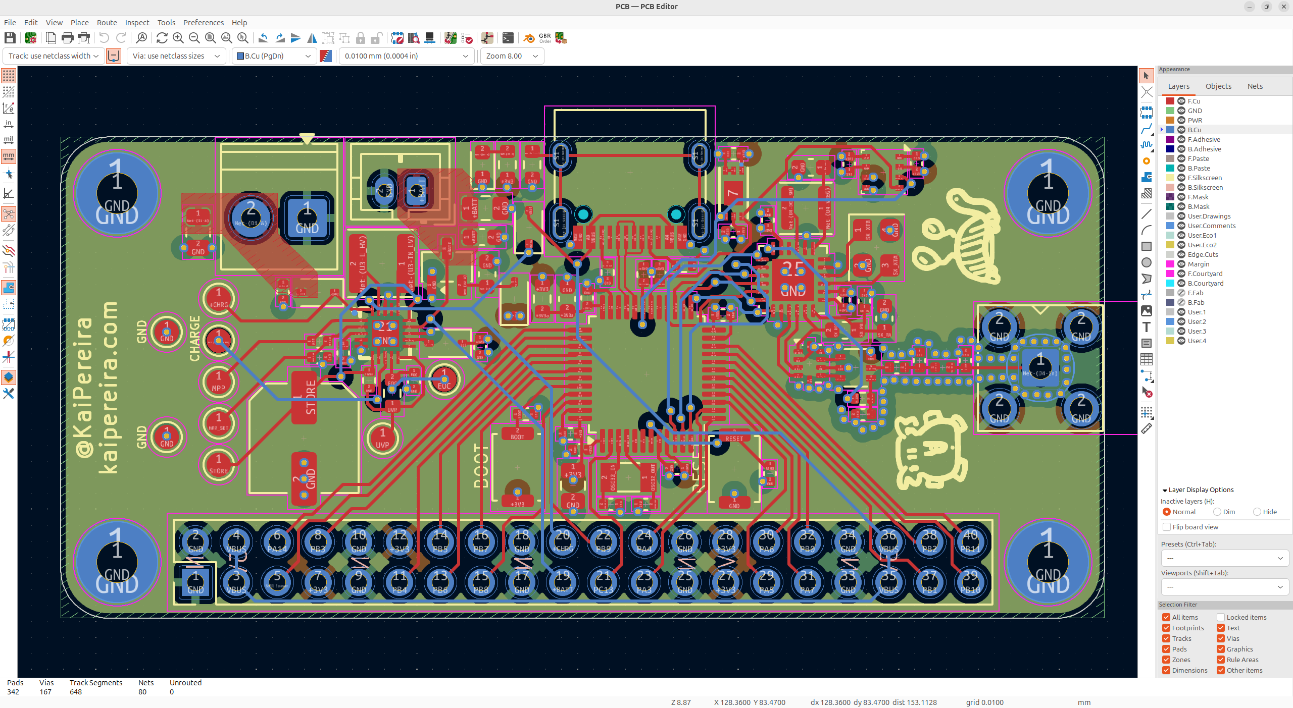
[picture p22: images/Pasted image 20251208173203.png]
Pasted image 20251208173203.png


It's not my prettiest work, but I think it's one of my more practical works. So let's talk about a couple different parts here:
- USB is a 90ohm differential pair, this doesn't really matter too much, but I did it anyways
- The antenna has a via fence to isolate the signal
- Trying to keep my ground loops smaller. I've been trying to think of all my IC's and whatnot as squares and shapes, instead of just lines and minimizing the area of those shapes for more efficient routing. You can see this in spot like the decoupling caps, where I minimize the square, to minimize inductance
- Keeping test pads accessible and clean
- Making the board at least look decent
- Made sure the RF trace was 50 ohm impedance (calculated this in the KiCad calculator!)

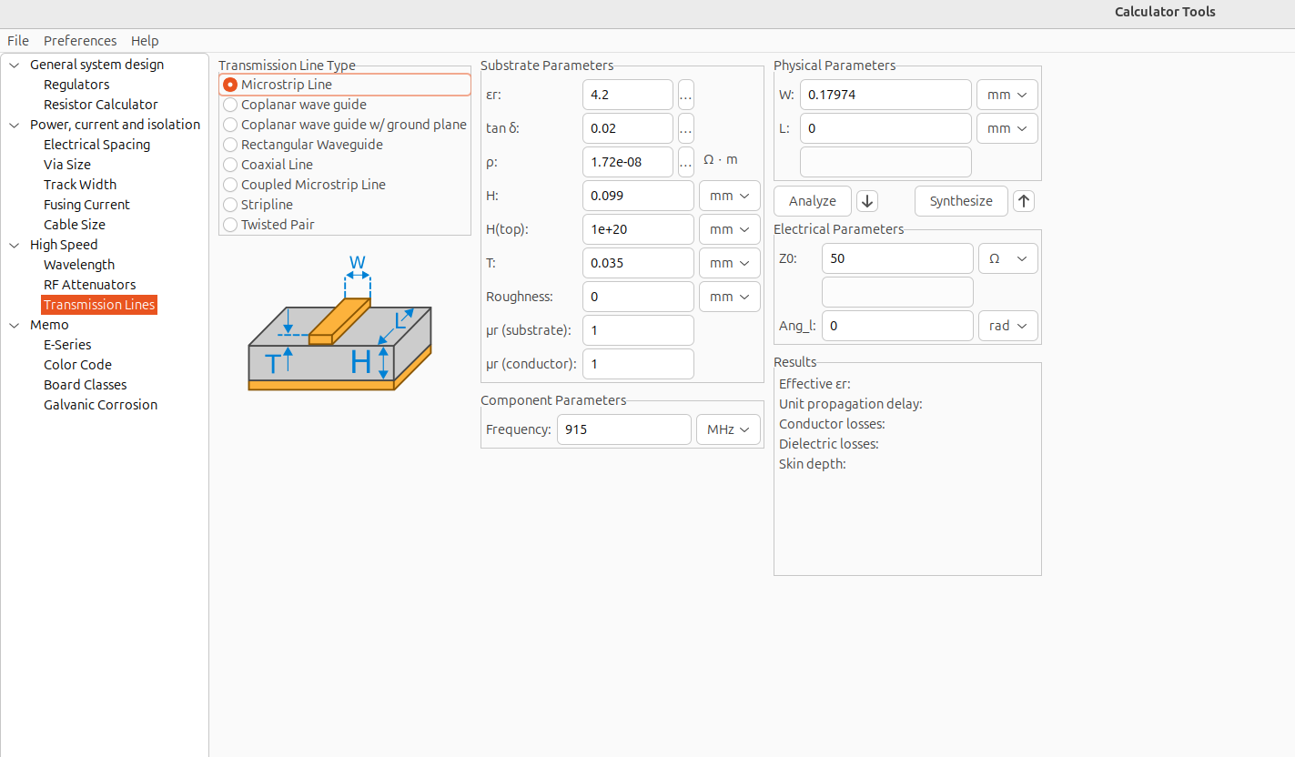
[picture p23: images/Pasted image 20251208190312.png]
Pasted image 20251208190312.png


And just like that, we're pretty much done the project! 

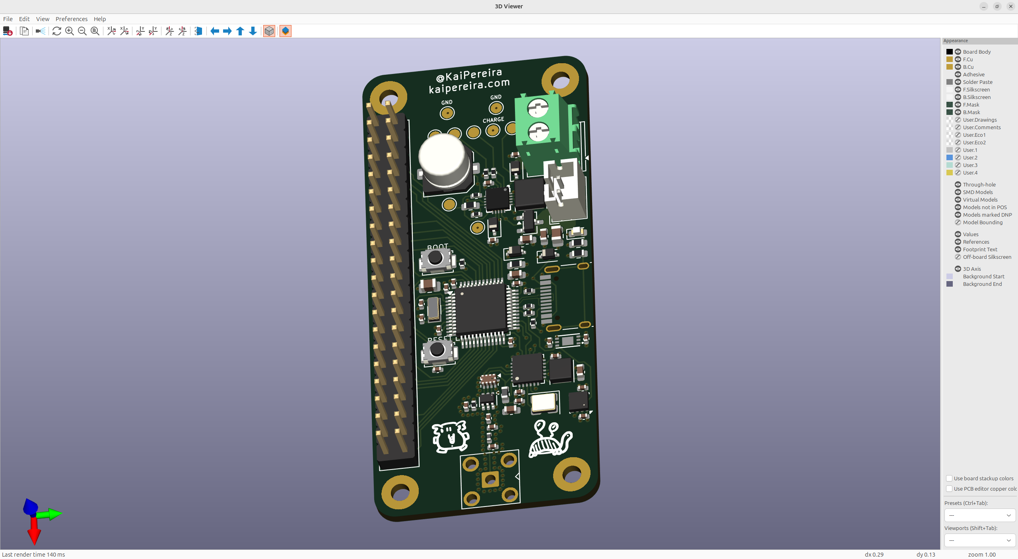
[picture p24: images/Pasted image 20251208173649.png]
Pasted image 20251208173649.png


So after that, I generated the production files, and then sent it in the kicad discord server for a PCB review. I think the project turned out pretty good, wasn't my best idea to be honest, but I learned a lot, and it was good practice! 

After all this, I created my readme and not I just have to get this thing production ready! I'm just going to be using JLCPCB, and it's a relatively simple board, so I'm not going to go into it much.

If you got to this point, send me a message over at kaipereira2020@gmaIl.com :D 

## Optimizing the board and making a BOM - 6 Hours

I thought this project was done, but it actually wasn't. I took a look at the PCB and it didn't quite fit the standards I hold to my work. This could be a genuinely cool project, but I wasn't putting the thought into it.

So let's get back into it and actually finish this project.

The first thing I actually did was to fix up the routing, fills and some 3D models. The board looked bland on the top because it was missing a ground fill on the top and bottom which would make it look better and also clean up some of the noise inducted by the LoRa antenna. So this entailed: 
- Adding a ground fill to the top and bottom
- Tuning up some of the routing to be cleaner
- Adding ground stitching along the whole board
- Moving all the via-in-pads
- Cleaning up the inductor and other fills to be significantly lower inductance and more optimal

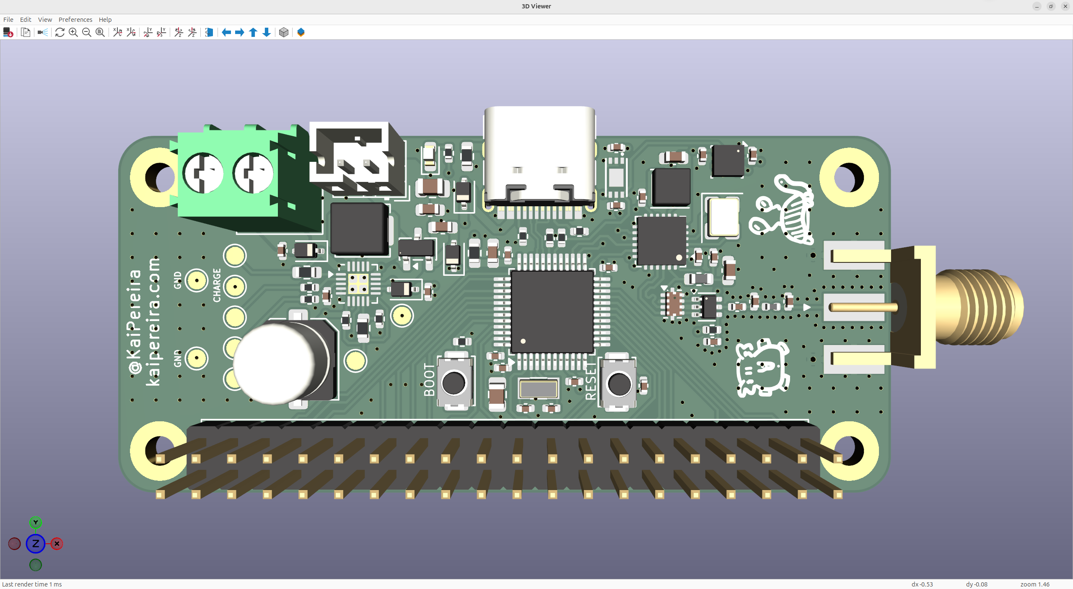
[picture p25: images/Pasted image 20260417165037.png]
Pasted image 20260417165037.png

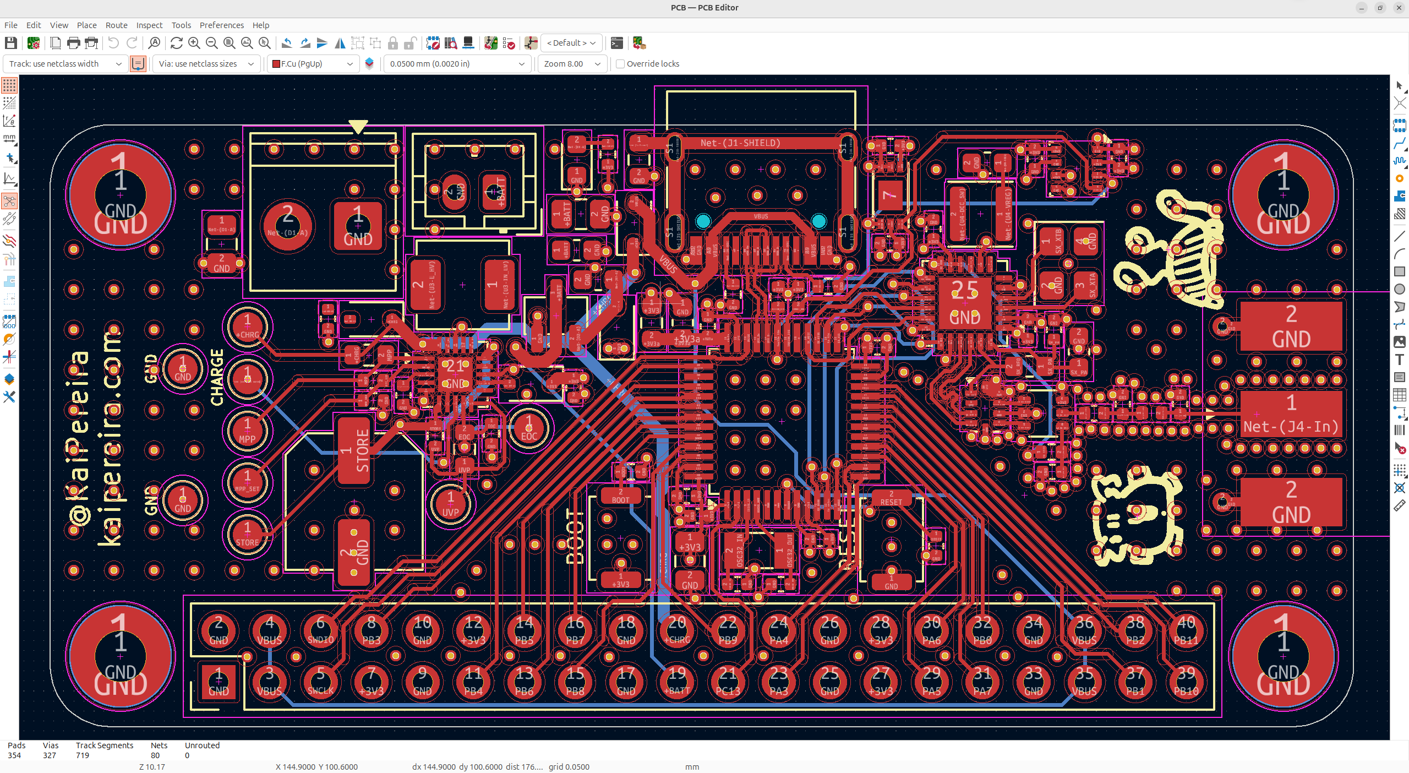
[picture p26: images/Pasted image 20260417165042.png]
Pasted image 20260417165042.png


Next, the reason I couldn't get this project manufactured was because JLC didn't have many of the parts like the filter, SMA stuff and it was all EXTREMELY expensive because it was all extended parts. So I created an entire BOM in digikey for 2 boards which took me quite a long time and also had to replace a ton of the parts, notably the inductors for other parts because they weren't available on digikey!

This also meant that I could get a ton of other components like my heatset inserts, spare connectors, just anything extra I would need for the project that didn't justify extra shipping!

So with all of that, my board looks significantly better, and I actually have a BOM that's ready to buy and comes out to about $150, perfect!

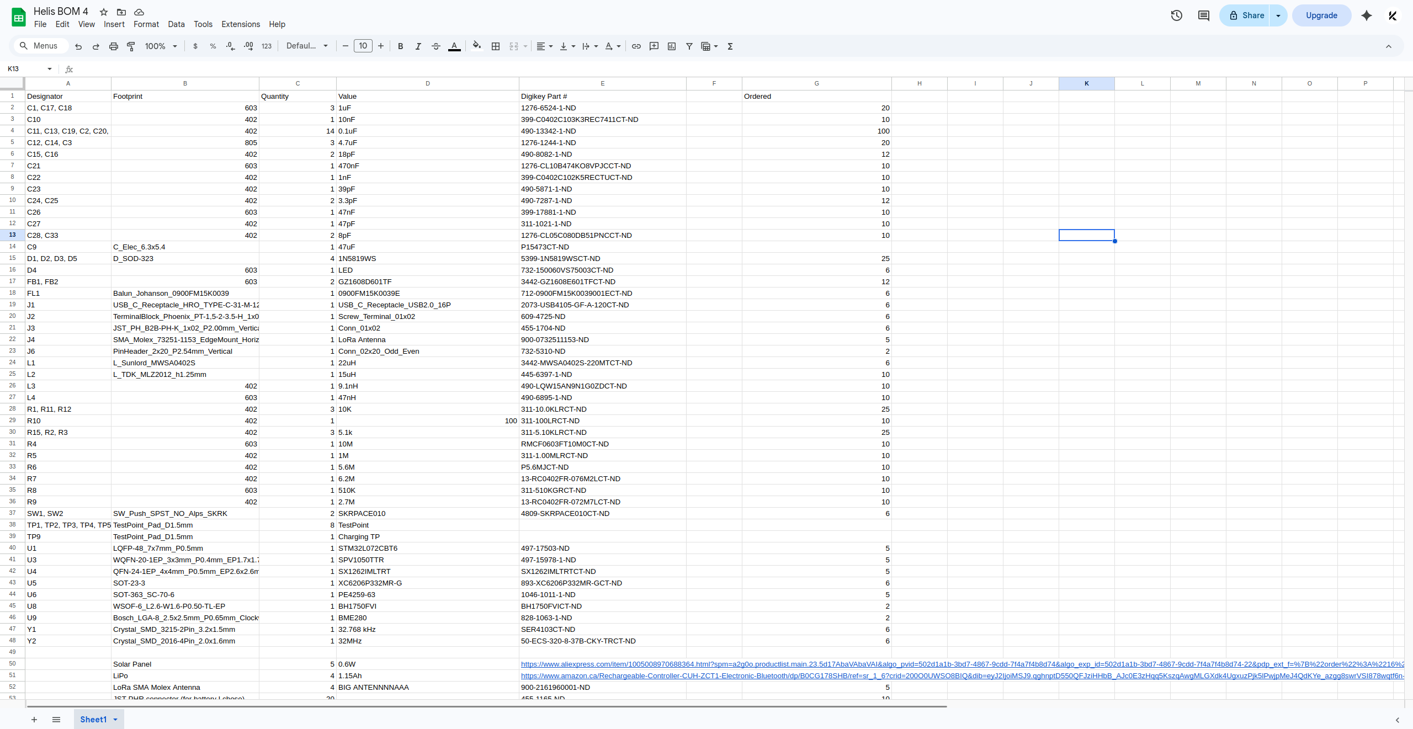
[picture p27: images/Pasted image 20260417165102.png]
Pasted image 20260417165102.png


Now this project is genuinely something I'm proud of, and is pretty gorgeous. The one thing I do wish that I had done, was making this whole thing cheaper. Now making it cheaper would've also made this easier. I could've just used a bunch of pre-made components and called it a day. But I definitely wouldn't have learned as much, so I'm honestly glad I spent the extra money, and time to learn matching networks, filters, etc. 

## CAD and more BOM shenanigans - 8 Hours

Now that my BOM was pretty much done, I wanted to work on something that could tangibly hold the devboard if I wanted to leave it outside or something. 

I did a relatively simple design that took me a bit longer than I do want to admit, but I think it turned out really practical! It has a large hole for the antenna, some waterproofing design, and a little hole at the top for the solar panel.

I really want to use this thing as a weather station for the my website, so this will allow me to do just that! I also got a little fancy and added some heatset inserts and modelled in the components, and it turned out pretty nice:

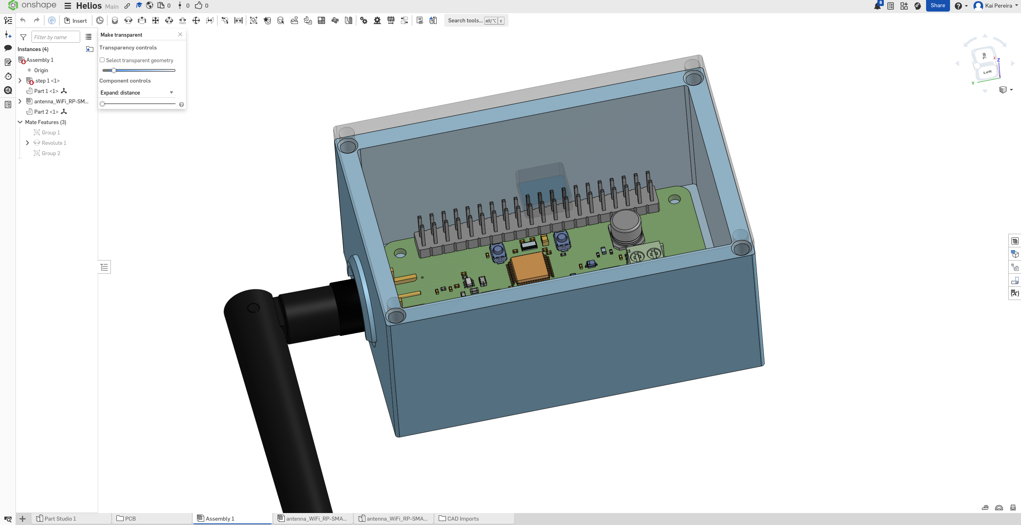
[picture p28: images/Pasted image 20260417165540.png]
Pasted image 20260417165540.png


I added some other things to my BOM like the heatset inserts for this project, and the antenna, etc. And I also fixed some of the unavailable items like the crimps and whatnot.

Now that I've actually created my BOM, I wanted to get a sponsorship from PCBWay. My board is quite complicated, and costs a lot from digikey, so getting PCBWay to sponsor maybe $150, would go an absolutely long way and then I wouldn't even need to hand solder the board! PCBWay was already asking to do a sponsorship with me, but I didn't realize that they accepted digikey BOM's, so after making some alterations they asked for like what was up with some of the loose parts, and DNP's, they finally sponsored me for $150!

It took quite a long time to get this through, but I'm really glad I got the project sponsored because now I can get 5 boards instead of just 2! 

The case isn't the prettiest so I'll just include the files, and not show it off on my repository, but it's practical and gets the job done!

I'm really proud with how I turned around this project. The polish and manufacturing was really getting to my head, and the experienced I've gained from my FPGA board really allowed me to get a final product I'm happy with.

I'm definitely going to be exploring RF some more, because this was so much fun to tune up and I learned a ton from it!

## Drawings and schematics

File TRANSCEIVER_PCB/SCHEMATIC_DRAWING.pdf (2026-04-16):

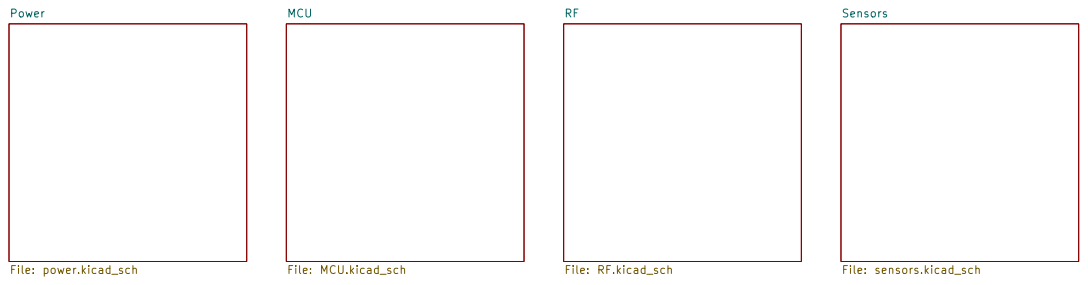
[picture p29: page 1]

Size: A4 | Rev:
KiCad E.D.A. 10.0.0 | Id: 1/5

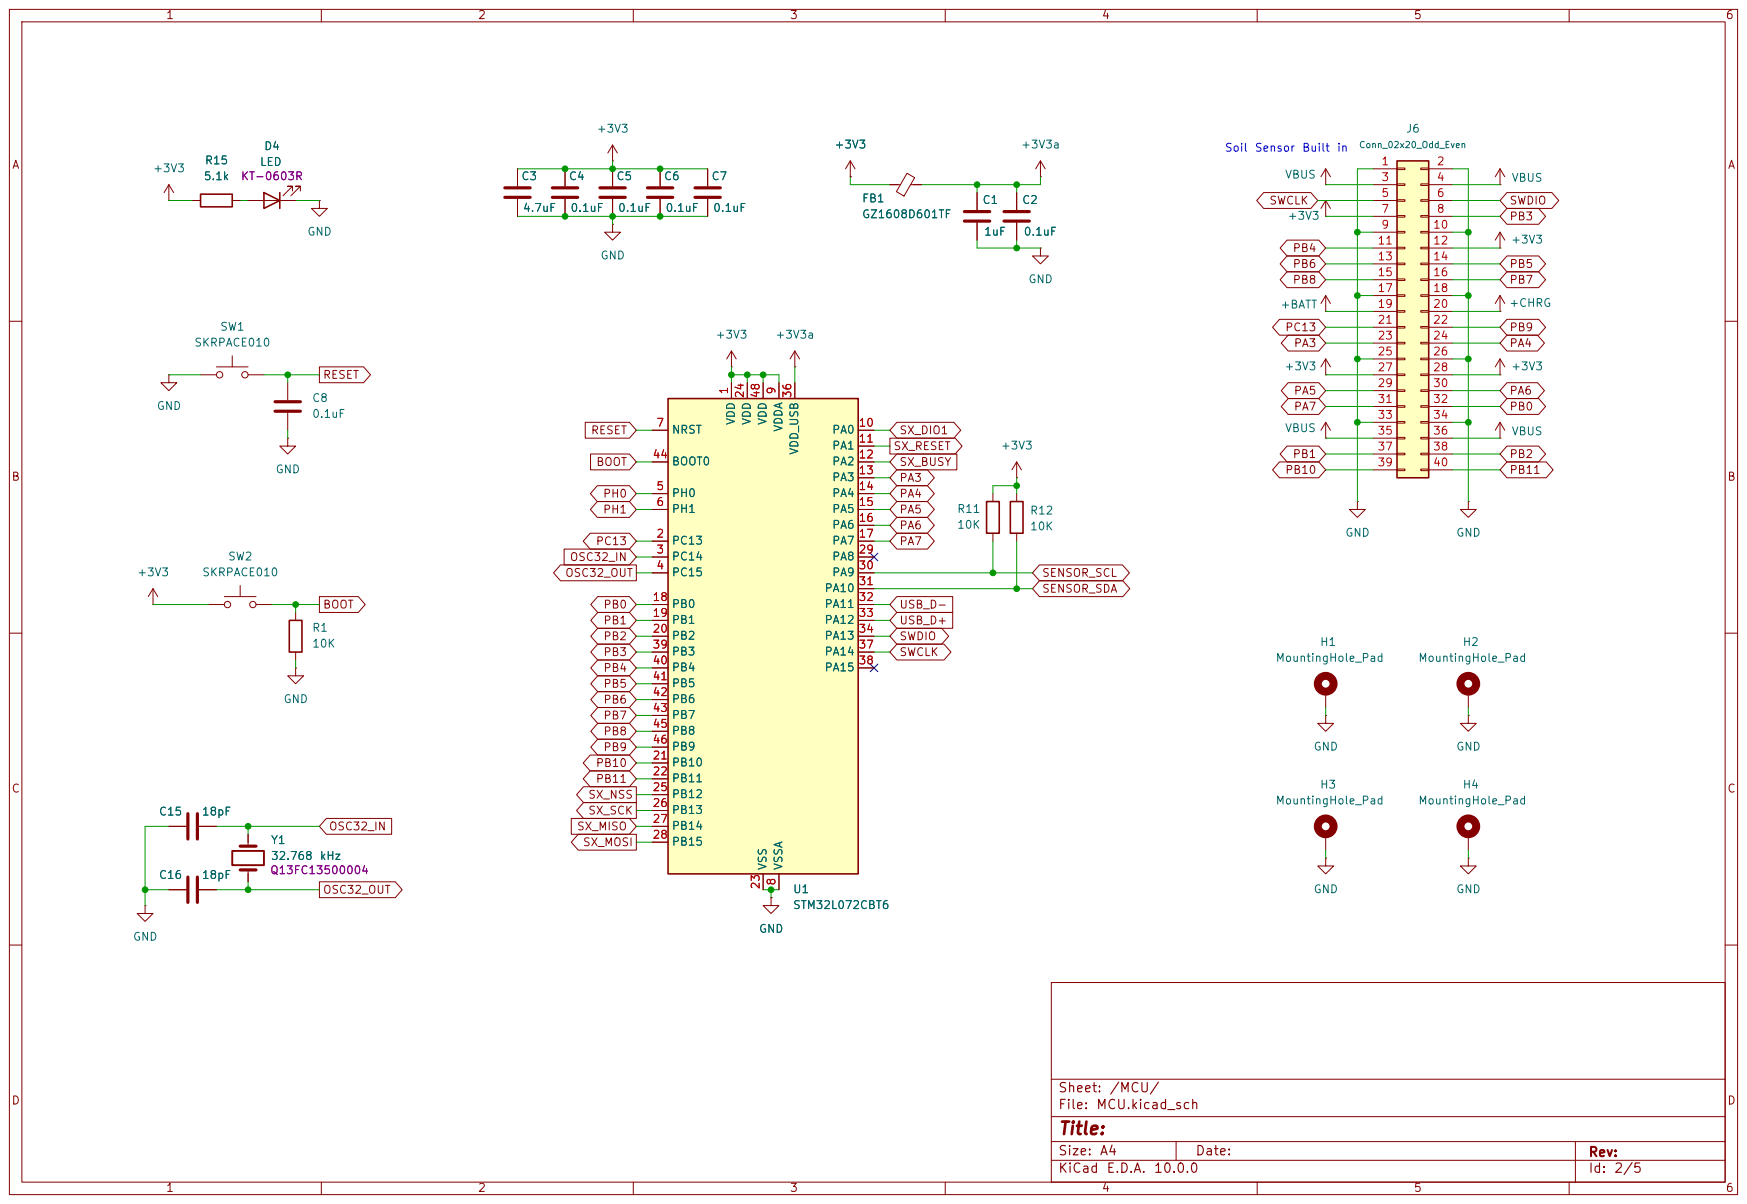
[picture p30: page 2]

Soil Sensor Built in C2

9 | 10
11 | 12
13 | 14
15 | 16
17 | 18
19 | 20
21 | 22
23 | 24
25 | 26
27 | 28
29 | 30
31 | 32
33 | 34
35 | 36
37 | 38
39 | 40

1 PC13 2 PC14 3 PC15 4 PH0 5 PH1 6 NRST 7 VSSA 8 VDDA 9 PA0 10 PA1 11 PA2 12 PA3 13 PA4 14 PA5 15 PA6 16 PA7 17 PB0 18 PB1 19 PB2 20 PB10 21 PB11 22 VSS 23 VDD 24 PB12 25 PB13 26 PB14 27 PB15 28 PA8 29 PA9 30 PA10 31 PA11 32 PA12 33 PA13 34 VDD_USB 36 PA14 37 PA15 38 PB3 39 PB4 40 PB5 41 PB6 42 PB7 43 BOOT0 44 PB8 45 PB9 46 VDD 48 U1

1 PC13 2 PC14 3 PC15 4 PH0 5 PH1 6 NRST 7 VSSA 8 VDDA 9 PA0 10 PA1 11 PA2 12 PA3 13 PA4 14 PA5 15 PA6 16 PA7 17 PB0 18 PB1 19 PB2 20 PB10 21 PB11 22 VSS 23 VDD 24 PB12 25 PB13 26 PB14 27 PB15 28 PA8 29 PA9 30 PA10 31 PA11 32 PA12 33 PA13 34 VDD_USB 36 PA14 37 PA15 38 PB3 39 PB4 40 PB5 41 PB6 42 PB7 43 BOOT0 44 PB8 45 PB9 46 VDD 48 GND

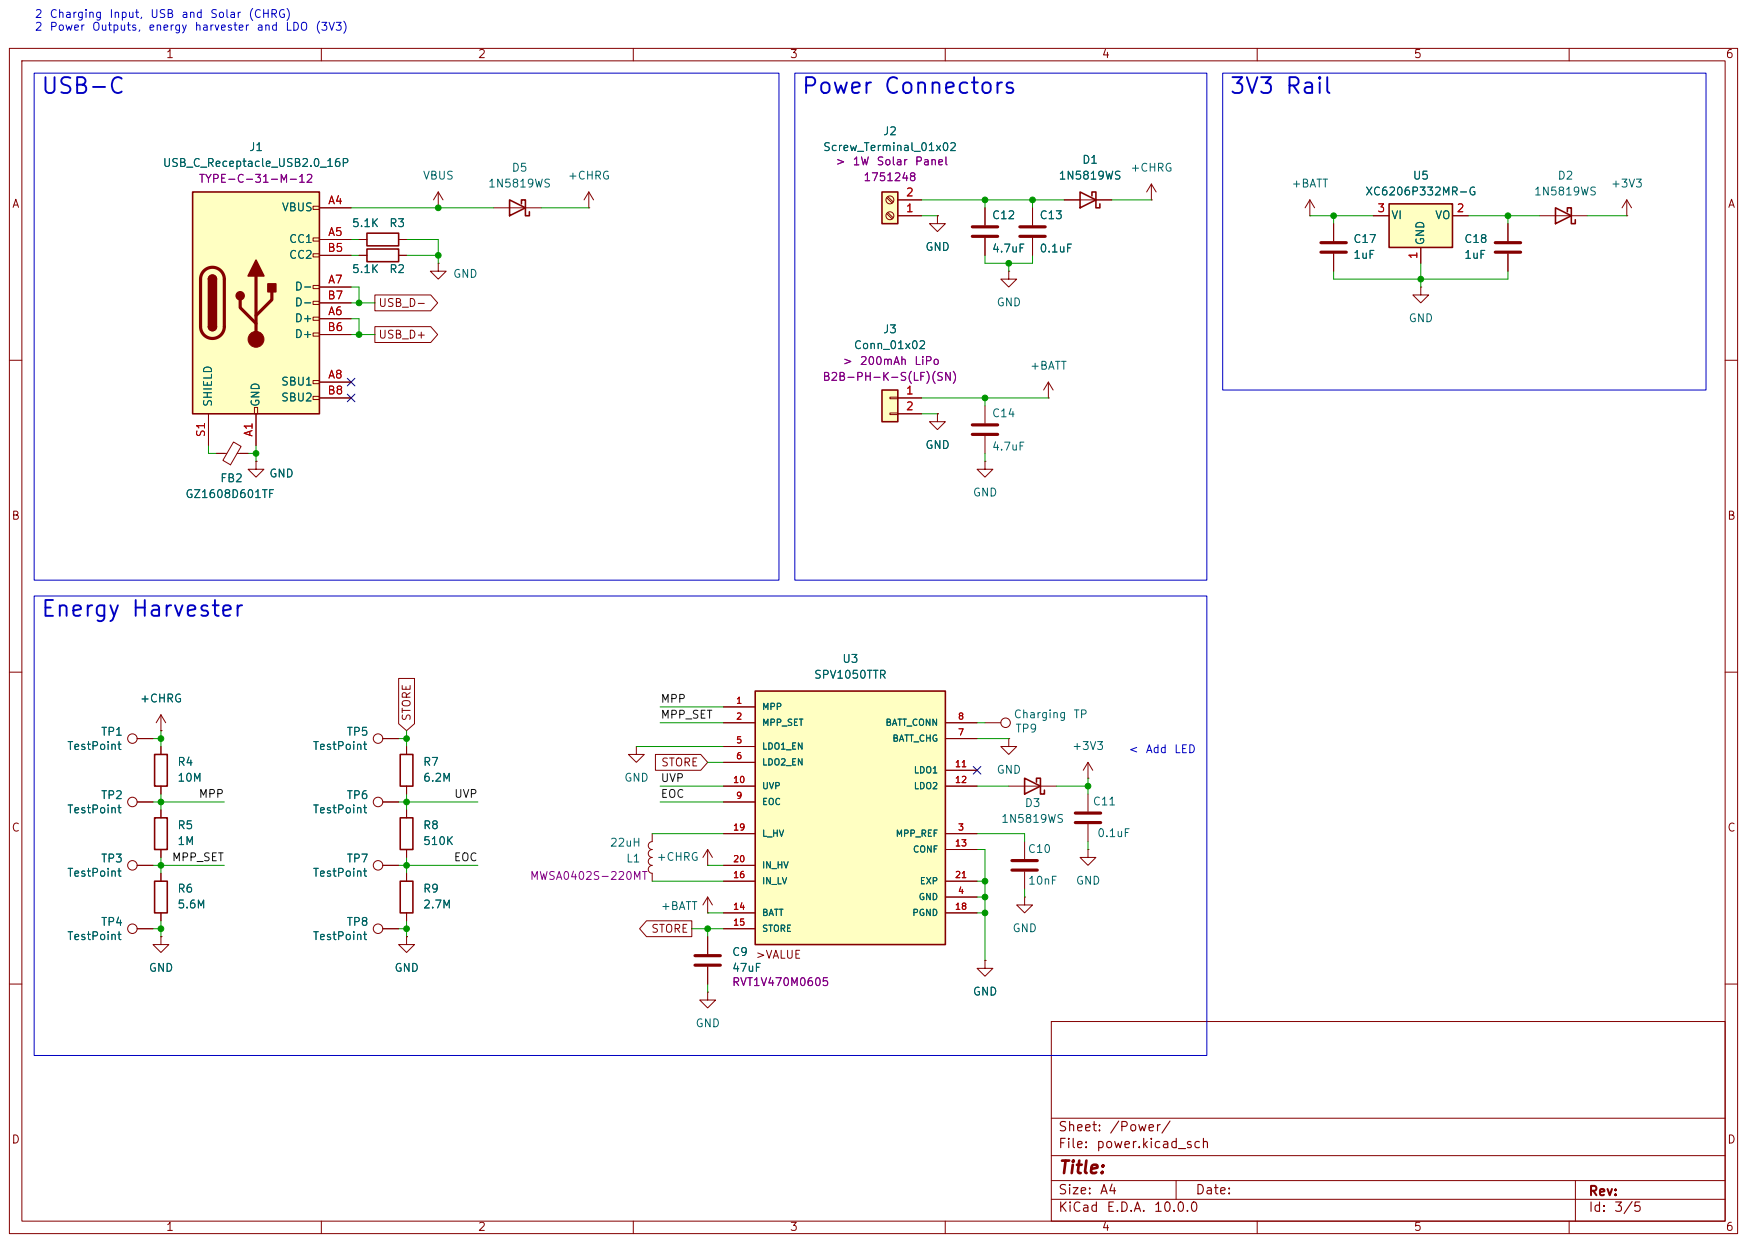
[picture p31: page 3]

2 Charging Input, USB and Solar (CHRG)
TYPE-C-31-M-12 GND A1

J3 Conn_01x02 > 200mAh LiPo B2B-PH-K-S(LF)(SN) 1

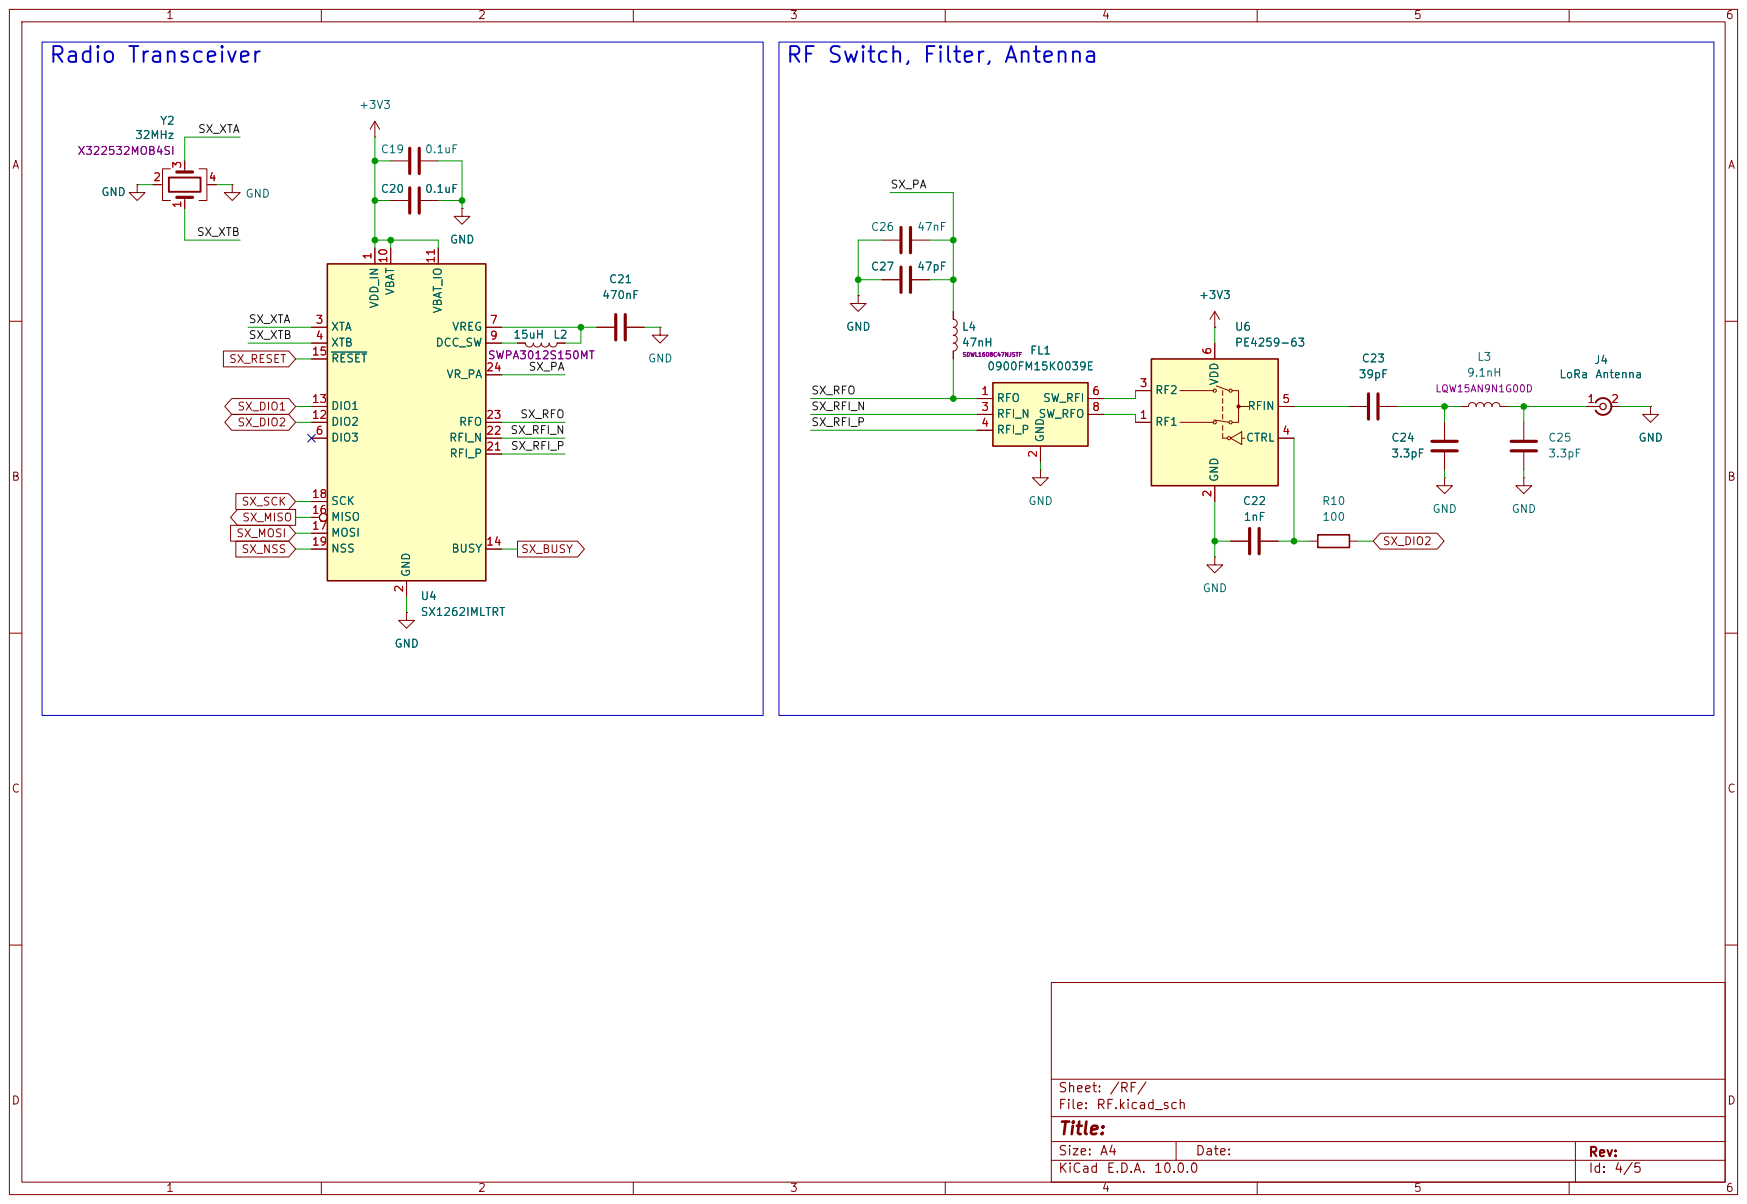
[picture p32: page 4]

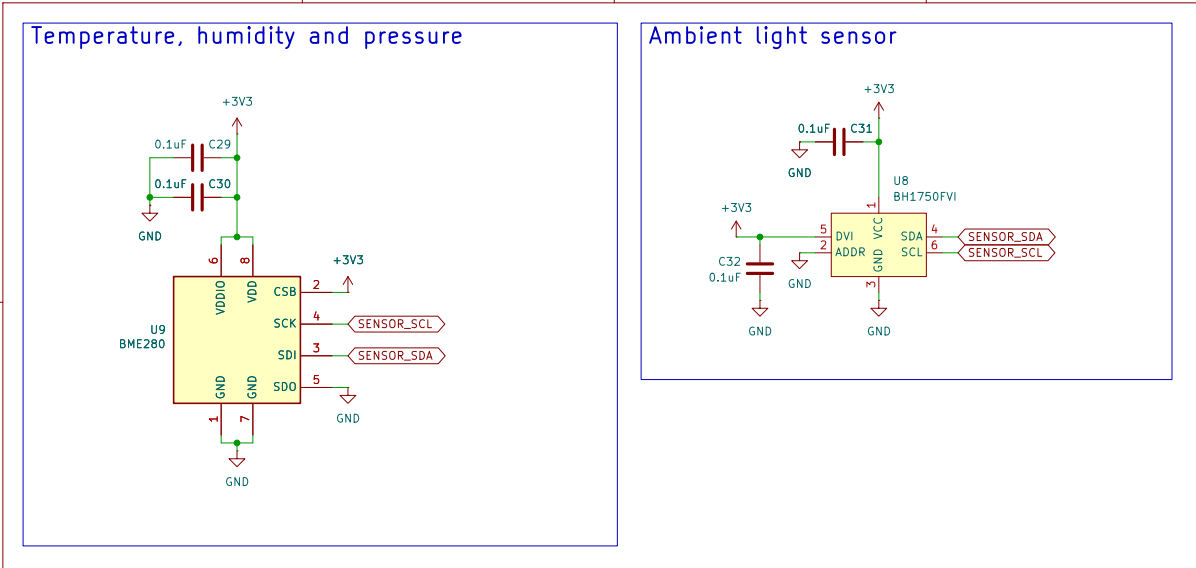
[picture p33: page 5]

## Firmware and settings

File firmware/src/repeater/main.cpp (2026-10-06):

#include "RadioConfig.h"

volatile bool packetReceived = false;

void onPacket(void) {
	packetReceived = true;
}

void setup() {
	Serial.begin(115200);

	while (!Serial && millis() < 5000); // Serial takes a minute to enumerate

	radio.tcxoVoltage = 0; // Using an external crystal so set to 0V

	Serial.print(F("[SX1262] Starting Up..."));

	config.frequency = NODE_CHANNEL;
	
	int state = radio.begin(config);

	if (state == RADIOLIB_ERR_NONE) {
		Serial.println(F("Success!"));
	} else {
		Serial.print(F("Failed!"));
		Serial.println(state);
	}

	radio.setDio2AsRfSwitch(true); // Sets the RF switch to receive
	radio.setPacketReceivedAction(onPacket);

	Serial.print(F("[SX1262] Listening..."));
	state = radio.startReceive();

	if (state == RADIOLIB_ERR_NONE) {
		Serial.println(F("Success!"));
	} else {
		Serial.print(F("Failed!"));
		Serial.println(state);
	}
}

void loop() {
	if (packetReceived) {
		packetReceived = false;

		String message;
		int state = radio.readData(message); // Reads data into the message

		if (state == RADIOLIB_ERR_NONE && message.startsWith("id=")) {
			message += " rs=" + String((int)radio.getRSSI());

			Serial.print(F("[Relay] Trying..."));
			Serial.println(message);

			radio.setFrequency(LINK_CHANNEL);

			int radio_state = radio.transmit(message);

			if (radio_state == RADIOLIB_ERR_NONE) {
				Serial.println(F("[Relay] Successfully Repeated!"));
			} else {
				Serial.print(F("[Relay] Failed"));
				Serial.println(radio_state);
			}
		} else {
			Serial.print(F("[SX1262] Failed: "));
			Serial.println(state);
		}

		radio.startReceive();
	}
}

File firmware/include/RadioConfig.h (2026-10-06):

#include <Arduino.h>
#include <SPI.h>
#include <RadioLib.h>

ConfigLoRa_t config;

const int SX_SCLK = PB13;
const int SX_MISO = PB14;
const int SX_MOSI = PB15;
const int SX_NSS = PB12;
const int SX_BUSY = PA2;
const int SX_RESET = PA1;
const int SX_DIO_1 = PA0;

const int SENSOR_SDA = PA10;
const int SENSOR_SCL = PA9;
const uint8_t BME280_ADDR = 0x76;
const uint8_t BH1750_ADDR = 0x23;

// different frequencies to prevent interference
// Standard about 915 for North America
const float NODE_CHANNEL = 915.0;
const float LINK_CHANNEL = 916.0;

SPIClass SPI_LORA(SX_MOSI, SX_MISO, SX_SCLK);
SX1262 radio = new Module(SX_NSS, SX_DIO_1, SX_RESET, SX_BUSY, SPI_LORA);

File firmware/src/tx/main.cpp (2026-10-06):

#include "RadioConfig.h"
#include <BH1750.h>
#include <Adafruit_BME280.h>
#include <Adafruit_Sensor.h>
#include <Wire.h>

// Macro to make each device id easy to name
#ifndef NODE_ID
#error "NODE_ID not set, please set one using -D NODE_ID=<number> to your build flags"
#endif

Adafruit_BME280 bme280;
BH1750 bh1750;

bool bme280_state;
bool bh1750_state;

uint32_t messageCount = 0;

void setup() {
	Serial.begin(115200);

	while (!Serial && millis() < 5000); // Serial takes a minute to enumerate

	
	// Sensors
	Wire.setSDA(SENSOR_SDA);
	Wire.setSCL(SENSOR_SCL);
	Wire.begin();
	
	Serial.println(F("[BME280] Starting Up..."));

	bme280_state = bme280.begin(BME280_ADDR, &Wire);

	Serial.println(bme280_state ? "Success!" : "Failed!");


	Serial.println("[BH1750] Starting Up...");
	
	bh1750_state = bh1750.begin(BH1750::CONTINUOUS_HIGH_RES_MODE, BH1750_ADDR, &Wire);

	Serial.println(bh1750_state ? "Success!" : "Failed!");

	
	// LoRa Radio
	radio.tcxoVoltage = 0; // Using an external crystal so set to 0V

	config.frequency = NODE_CHANNEL;
	
	Serial.print(F("[SX1262] Starting Up..."));

	int radio_state = radio.begin(config);

	if (radio_state == RADIOLIB_ERR_NONE) {
		Serial.println(F("Success!"));
	} else {
		Serial.print(F("Failed:"));
		Serial.println(radio_state);
	}
}

void loop() {
	String message;

	String msg = "id=" + String(NODE_ID) + " n=" + String(messageCount++);
 
	if (bme280_state) {
		msg += " T=" + String(bme280.readTemperature(), 1);
		msg += " H=" + String(bme280.readHumidity(), 1);
		msg += " P=" + String(bme280.readPressure() / 100.0F, 1);
	}
 
	if (bh1750_state) {
		msg += " L=" + String(bh1750.readLightLevel(), 1);
	}

	Serial.println(message);

	int radio_state = radio.transmit(message);

	Serial.print(F("[SX1262] TX: "));
	Serial.println(radio_state == RADIOLIB_ERR_NONE ? F("Success!") : F("Failed"));
	
	delay(5000);
}

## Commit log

2025-11-26 re-doing this, somehow messed up git
    [PCB.kicad_pcb, PCB.kicad_sch]
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2025-11-26 a bunch of journaling
    [PCB.kicad_sch]
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2025-11-27 starting on solar panel stuff
    [power.kicad_sch]
2025-11-27 updating the journal with mcu and power stuff!
    [power.kicad_sch]
2025-11-27 adding in my energy harvester!
    [power.kicad_sch]
2025-11-27 using a better symbol
    [power.kicad_sch]
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2025-11-27 trying to wire the SPV1050
    [power.kicad_sch]
2025-11-28 almost done wiring the energy harvester!
    [power.kicad_sch]
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2025-11-28 finished wiring the SPV1050!
    [power.kicad_sch]
2025-11-28 adding in antenna and cleaning up power schematic
    [MCU.kicad_sch, PCB.kicad_sch, RF.kicad_sch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]
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2025-11-29 fixed the crystal
    [MCU.kicad_sch, PCB.kicad_sch, power.kicad_sch]
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2025-11-30 done half the wiring of the SX!g
    [RF.kicad_sch]
2025-11-30 SX fully wired to MCU
    [MCU.kicad_sch, RF.kicad_sch]
2025-11-30 added the RF switch, and cleaned stuff up!
    [MCU.kicad_sch, RF.kicad_sch]
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2025-12-01 fixed value's, wiring filter
    [RF.kicad_sch]
2025-12-01 finished the rf switch, filter and antenna!
    [RF.kicad_sch]
2025-12-01 starting on sensors, cleaning stuff up!
    [PCB.kicad_sch, RF.kicad_sch, power.kicad_sch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]
2025-12-01 finished wiring the capacitative soil sensor, moved a bunch of labels for more analog!
    [MCU.kicad_sch, RF.kicad_sch, sensors.kicad_sch]
2025-12-01 adding the BME280 sensor
    [MCU.kicad_sch, sensors.kicad_sch]
2025-12-01 adding the BH1750 sensor in!
    [MCU.kicad_sch, power.kicad_sch, sensors.kicad_sch]
2025-12-01 cleaning up stuff, fixing typos!
    [MCU.kicad_sch, sensors.kicad_sch]
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2025-12-02 saving before changing commits to fix the energy harvester symbol
    [sensors.kicad_sch]
2025-12-02 fixed the symbol
    [power.kicad_sch]
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2025-12-03 adding more parts and reducing BOM
    [MCU.kicad_sch, power.kicad_sch]
2025-12-03 assigned all the capacitor footprints!
    [MCU.kicad_sch, RF.kicad_sch, power.kicad_sch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]
2025-12-03 standardized resistors and added footprints!
    [MCU.kicad_sch, RF.kicad_sch, power.kicad_sch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]
2025-12-03 adding some module and test point footprints
    [MCU.kicad_sch, power.kicad_sch, sensors.kicad_sch]
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2025-12-04 added ALL the footprints!
    [MCU.kicad_sch, RF.kicad_sch, power.kicad_sch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]
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2025-12-04 adding a status LED and cleaning up the board
    [MCU.kicad_sch, PCB.kicad_pcb]
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2025-12-04 re-wiring everything for easier routing
    [MCU.kicad_sch, PCB.kicad_pcb]
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2025-12-05 adding USB programming and sharing the I2C bus
    [MCU.kicad_sch, sensors.kicad_sch]
2025-12-05 re-did the pin headers, nice and organized
    [MCU.kicad_sch, PCB.kicad_pcb]
2025-12-06 changed header pins to be like the 02w
    [MCU.kicad_sch, PCB.kicad_pcb]
2025-12-06 fixing a schematic mistake
    [MCU.kicad_sch, PCB.kicad_pcb, power.kicad_sch]
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2025-12-06 turned it into the pi pico form factor
    [PCB.kicad_pcb]
2025-12-06 fixing the pi pico form factor
    [PCB.kicad_pcb]
2025-12-06 updating the journal with finished schematic
    [PCB.kicad_pcb]
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2025-12-06 grouped all the components together
    [PCB.kicad_pcb]
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2025-12-07 working on aligning the antenna
    [PCB.kicad_pcb, RF.kicad_sch]
2025-12-07 built the soil sensor into the pin headers
    [MCU.kicad_sch, PCB.kicad_pcb, sensors.kicad_sch]
2025-12-07 finishing the antenna layout
    [PCB.kicad_pcb]
2025-12-07 fixing the charging schematic and organizing the charging components a bit
    [PCB.kicad_pcb, power.kicad_sch]
2025-12-07 backup up for the day
    [PCB.kicad_pcb]
2025-12-07 laying out the solar components
    [PCB.kicad_pcb, power.kicad_sch]
2025-12-07 layed out the solar and battery charging
    [PCB.kicad_pcb]
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2025-12-07 all the main components layed out
    [PCB.kicad_pcb]
2025-12-07 switching to 4 layer board, adding fills
    [MCU.kicad_sch, PCB.kicad_pcb]
2025-12-07 a bunch of routing
    [PCB.kicad_pcb]
2025-12-07 working on routing power!
    [PCB.kicad_pcb]
2025-12-07 fixing the USB schematic
    [MCU.kicad_sch, PCB.kicad_pcb]
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2025-12-08 starting to route sensors and rf
    [PCB.kicad_pcb]
2025-12-08 aligned the antenna more nicely
    [PCB.kicad_pcb]
2025-12-08 re-doing lots of the antenna routing
    [PCB.kicad_pcb]
2025-12-08 re-routing to header piuns and adding in the last button!
    [PCB.kicad_pcb]
2025-12-08 hoping off for the day, did some more RF routing!
    [PCB.kicad_pcb]
2025-12-08 re-doing the antenna and routing it
    [PCB.kicad_pcb, RF.kicad_sch]
2025-12-08 routed all the sensors
    [PCB.kicad_pcb]
2025-12-08 more routing, adding in the test points too
    [PCB.kicad_pcb]
2025-12-08 just 4 more things to route!
    [PCB.kicad_pcb]
2025-12-08 everything routed, DRC time :((
    [PCB.kicad_pcb]
2025-12-08 did some re-routing, no more DRC errors!
    [PCB.kicad_pcb]
2025-12-08 added the via fence to the antenna
    [PCB.kicad_pcb]
2025-12-08 cleaning up silkscreen and labelling some stuff
    [PCB.kicad_pcb]
2025-12-09 added all the silkscreen art in
    [PCB.kicad_pcb]
2025-12-09 added in production files
    [bom.csv, designators.csv, positions.csv]
2025-12-09 pushing all the changes
    [PCB.kicad_pcb]
2025-12-09 standardizing components for prod and new fab files
    [positions.csv, power.kicad_sch]
2025-12-09 fixing impedance on the SX1262
    [PCB.kicad_pcb, RF.kicad_sch]
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2025-12-09 fixed the RF trace again, added new prod files!
    [PCB.kicad_pcb]
2025-12-09 finished USB differential pairs
    [PCB.kicad_pcb]
2025-12-09 adding the JLCPCB BOM
    [JLCPCB_BOM.xls, power.kicad_sch]
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2026-04-09 working through DRC errors
    [MCU.kicad_sch, PCB.kicad_pcb, PCB.kicad_sch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]
2026-04-10 fully breaking out SWWD!
    [MCU.kicad_sch, PCB.kicad_pcb]
2026-04-10 fab files, let's get a BOM together now!
    [PCB.kicad_pcb, bom.csv, positions.csv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]
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2026-04-11 tightening up transceiver routing
    [PCB.kicad_pcb]
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2026-04-14 new inductor and some routing improvements (I really need to finish this though :)
    [PCB.kicad_pcb]
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2026-04-16 plotting schematic PDF and cleaning up PROD files
    [JLCPCB_BOM.xls, MCU.kicad_sch]
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2026-04-17 journaling about fixing the PCB and making the BOM!
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2026-10-04 fixing typo and updating README with firmare stuff
    [main.cpp]
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
